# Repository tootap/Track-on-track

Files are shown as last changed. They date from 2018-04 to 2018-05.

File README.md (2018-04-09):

# Track-on-track

This is our ECE 477 senior design project.

Track-on-Track is a project which helps users to find their belongings. It is placed with a user’s belonging and uses a GSM module to connect with a phone app which shows the location of the device. A smartphone application will be available to allow the user to interact with the device but it can also be interacted with through GSM.  When the device is in shorter range, it uses a bluetooth module and shows on the app whether the user is getting closer to the device. The user will be able to see the device’s location, activate a sound alarm on the device, and manipulate the devices settings remotely. The user will also be able to interact with the device’s settings through various buttons and an LCD on the device.

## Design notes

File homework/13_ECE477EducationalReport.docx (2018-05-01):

## Purdue ECE Senior Design Semester Report

Course Number and Title | ECE 477 Digital Systems Senior Design Project
Semester / Year | Spring 2018
Advisors | Prof. Thottethodi, George Hadley
Team Number | 16
Project Title | Track-on-Track

##### Senior Design Students – Team Composition

Name | Major | Area(s) of Expertise Utilized in Project | Expected Graduation Date
Nicholas Geirland | CmpE | Firmware, Soldering | Spring 2018
Nathan McNally | CmpE | Software | Spring 2018
Yunsheng Li | EE | Schematics, PCB Layout | Spring 2018
Aaron Kaiser | CmpE | Software, Design | Spring 2018

Project Description: Provide a brief (2-3 page) technical description of the design project, as outlined below:

(a) Summary of the project, including customer, purpose, specifications, and a summary of the approach.

Track-on-track is a project designed to create a device which is capable of transmitting its location to the user through SMS messages, and which is also able to communicate relative distance to the user through bluetooth. In addition, the device will contain a speaker which will be used for finding the device audibly. The project also included a smartphone application, which is the primary means of communicating with the user. The purpose of the device is to locate lost or stolen bags, luggage, or other containers which may contain valuables. This product is designed for anyone who carries valuables with them in bags that they would not want to lose, and in particular, it is designed for travelers. Some specifications for the project were to make it small and light enough to be able to fit into most bags and not be difficult to carry. Another major concern was battery life, as the device was supposed to go into a bag and stay there for multiple weeks at a time. Other considerations included the strength of the signal of both the cell modem and the bluetooth, as more power means a more reliable device. In the end, the GSM cell modem and bluetooth module were both chosen to balance the need for power with the need for battery life. A microcontroller was selected based on its ability to preserve power, as not many heavy calculations were required for this design.

(b) Description of how the project built upon the knowledge and skills acquired in earlier ECE coursework.

Multiple courses helped the team prepare for this design. The whole device was designed around using a microcontroller to control flow between the different communication devices, and also to interpret and answer requests from the user. ECE 362 was the introductory microcontroller course at Purdue, and it covered the basics of programming a microcontroller and using it to interface with various devices. That course also had an opportunity to learn about and produce a PCB, which was the team’s first introduction to custom making PCBs. ECE 264 is a CompE required course which covers advanced C programming. This course also introduced many structures, methods, and concepts used in computer programming. The app for this design was an android app and was programmed in Java, but even so the concepts taught in ECE 264 assisted with developing the app. ECE 201 is an introductory circuits course which teaches the basics of circuit design with components such as capacitors, inductors, and resistors. While the concepts taught in this course are very basic, they were still required when calculating values of current limiting resistors and decoupling capacitors in the circuits.

(c) Description of what new technical knowledge and skills, if any, were acquired in doing the project.

In order to make progress in the project, new skills and knowledge was learned. For the hardware, the skills to use EAGLE CAD to design schematics and PCB layout were learned. Soldering is another skill that was learned and practiced a lot for each team member when building the board. Moreover, the important skill to debug hardware in a systematic way was acquired.

For software, the knowledge of how to communicate through Bluetooth module and GSM cell modem was learned. Also, the development of phone app required team members to learn the skills to program for android systems. The knowledge of using Google Maps in project’s app was also learned.

(d) Description of how the engineering design process was incorporated into the project. Reference must be made to the following fundamental steps of the design process: establishment of objectives and criteria, analysis, synthesis, construction, testing, and evaluation.

During the establishment of objectives and criteria stage of our project, we formulated a solution to a problem that was inspired by a situation in which a team member was directly impacted. We analyzed similar solutions and defined objectives that would meet the requirements for developing a product to solve the specific problem. As the project progressed, we conducted analysis on which hardware components would best fit our needs for meeting our objectives. Continuing with synthesis and construction, we began developing initial software, firmware, and schematics. Each separate hardware and software module was tested and brought online independently until the complete system was brought to fruition. As the various components were evaluated, there arose the need to return to the construction and testing stages until we could successfully demonstrate our complete design. The device was tested in an outdoor environment to ensure the testing modeled a real life situation.

(e) Summary of how realistic design constraints were incorporated into the project (consideration of most of the following is required: economic, environmental, ethical, health & safety, social, political, sustainability, and manufacturability constraints).

## Economic: The design took the cost into consideration to ensure the device is affordable for users by choosing relatively inexpensive parts and PCB manufacturer.

## Environmental: The device was designed to have a low environmental impact, creating no waste materials and no harmful radiation. This is achieved by choosing Lithium-ion rechargeable battery which results in no wasted batteries.

Ethical: The device has the potential to be used for unethical purposes such as stalking because the purpose of the device is luggage tracking. Although this kind of use cannot be directly prevented, the design will include warning tags that outlines the lawful results of using it for criminal purposes.

## Health & Safety: The safety problems on the device come only from the battery because the Bluetooth module and the cell modem used are certified to be harmless. The design prevents the battery from bringing harms by utilizing a sturdy package.

Social: During the development of project, it was brought to our attention that it was illegal to carry devices with lithium-ion batteries in checked luggage; however, through research, it was discovered that this is not the case. Traveling with spare (non-installed) lithium-ion batteries in checked luggage is prohibited, but devices with installed batteries are accepted in checked luggage.

## Political:

## Sustainability: The device was designed to communicate with user’s smartphone with Android system. Since Android smartphones have a large popularity in users, the device can be used by tons of users and as long as the app is downloaded, the device can be used to the end of its life cycle.

Manufacturability: Assuming that all chips and passive components can be soldered onto the PCB via an automatic process. The manufacturability of the device is great. Since most of the components are on board except the battery and antennas, once the board is manufactured, the only work left is to plug in the battery and antennas. Not only the assembly of the device is simple, it is also simple to swap the battery and antennas when they stop working.

(f) Description of engineering standards utilized in the project

Both the Bluetooth and GSM cell radio used in our project are certified by the FCC and CE. These components also utilize their respective standard communication protocols allowing for communication between the device and any mobile device that communicates using the standard communication protocols for cellular or Bluetooth, or both.

(g) Description of the multidisciplinary nature of the project.

This project required computer engineering knowledge and skills. The microcontroller is programed to interface with modules and process the commands to achieve desired functionalities. The phone app required knowledge of Java language to work together with the device. Moreover, electrical engineering knowledge was also required for the project to determine the circuit schematics design and values of passive components. Finally, some technical skills were used in building the prototypes such as soldering and EAGLE CAD software to design the PCB schematics and layout.

(h) Description of project deliverables and their final status.

The final prototype was able to achieve all the desired functions. It was able to communicate with smartphones via the phone app and show the location of the device using GPS. The device was able to send text messages to smartphones. Also, the device can be controlled to make sound through Bluetooth via the app. The pushbuttons and switches can successfully communicate with the microcontroller and enable the user to interact with device’s menus.

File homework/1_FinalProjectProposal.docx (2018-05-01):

# Final Project Proposal

# Year: 2018 Semester: Spring Team: 16 Project: Track-on-Track

# Creation Date: 1/10/2018 Last Modified: 1/10/2018

# Team Members (#1 is Team Leader):

# Member 1: Nick Geirland Email: ngeirlan@purdue.edu

# Member 2: Nathan McNally Email: nmcnall@purdue.edu

# Member 3: Yunsheng Li Email: li1436@purdue.edu

# Member 4: Aaron Kaiser Email: kaiser20@purdue.edu

# 1.0 Project Description:

Track-on-Track is a project which helps users to find their belongings. It is attached to user’s belonging and uses a SIM card module to connect with a phone app which shows the locations of the device. When the device is in shorter range, it uses a Bluetooth module and shows on the app whether the user is getting closer to the device. A smartphone application will allow the user to interact with the device. The user will be able to see the device’s location, activate a sound alarm on the device, and manipulate the devices settings remotely. The user will also be able to interact with the device’s settings through various buttons and an LCD on the device.

# 2.0 Roles and Responsibilities:

Nicholas Geirland will be the team leader for the project. This will involve making sure everyone is able to work on their portions of the project while also helping out with any design issues that may rise up. He is suited for this because he has been the team leader in all of his previous Computer Engineering class projects. He has also been the vice president of the Purdue Linux User Group since the end of his freshman year so leadership isn’t a new responsibility for him.

Nathan McNally has experience with both high level and low level programming languages. He has experience in Java, C, C++, assembly, and python. He has experience programming microcontrollers as well as working with phone apps. For these reasons, he will be the software engineer of the group, assisting in both microcontroller and app programming responsibilities.

Yunsheng Li will be the hardware engineer since he is highly interested in designing PCB and hardware aspects of the project. He is good at constructing circuit boards and doing math of circuits. He designed the circuit layout for his ECE 362 project. Also, he has some experience in using EAGLE for PCB design and 3D printing.

Aaron Kaiser will be the systems engineer due to his interest and experience in dealing with integrating software and hardware. He’s good at dealing with high level problems and assessing generic issues when they arise. He’s well versed in theories and concepts and in his past ECE 337 team he was responsible for creating many systems diagrams and tackling system wide bugs.

2.1 Homework Assignment Responsibilities

Homework responsibilities are detailed in Figure 1, below.

Design Component Homework | | Professional Component Homework
3-Software Overview | NG | 9-Legal Analysis | NM
5-Electrical Overview | YL | 10-Reliability and Safety Analysis | NG
7-Mechanical Overview | NM | 11-Ethical/Environmental Analysis | YL
8-Software Formalization | AK | 12-User Manual | AK

# Figure 1: Assignment Responsibilities

NG: Nicholas Geirland NM: Nathan McNally YL: Yunsheng Li AK: Aaron Kaiser

# 3.0 Estimated Budget

Item | Estimated Cost
Mechanical
Packaging | $5.00
Electrical
SIM Card | $9.00
Cell Modem | $70.00
PCB Fabrication | $50.00
PCB Components | $30.00
Rechargeable Battery | $40.00
Microcontroller | $20.00
Bluetooth Chip | $5.00
Antennae | $15.00
Other
Shipping | $50.00
Cell Service Package (2 mo. time period) | $20.00
Total Estimated Cost | $314.00

The first section is mechanical, which includes the physical non-electrical components of the device. For this project, this only includes packaging, as this design does not include any moving parts or major physical uses. The next section is electrical, which includes all physical hardware which is involved in electrical processes. For this project, this includes things involved in communication, such as a SIM card and a bluetooth chip, in addition to basic components such as a PCB and a microcontroller. The other category includes costs associated with services rather than physical items, and for this project includes shipping costs along with a cell service package.

The project is currently within the budget of $425 given by Purdue, but additional costs may be incurred throughout the development process, as components may be more expensive than anticipated, components may be broken during the testing phases, or because the PCB may have to be remade. If costs exceed the allotment of funds, additional costs will be split evenly among team members.

# 4.0 Project Specific Success Criteria

1. An ability to communicate with the user through Bluetooth in short distances.
2. An ability to communicate with the user through a cell modem over SMS in long distances.
3. An ability to display operating mode, battery life, and cell signal through an LCD.
4. An ability to detect the devices location.
5. An ability to control the device through a smartphone application.

https://engineering.purdue.edu/ece477 Page of

ECE 477: Digital Systems Senior Design Last Modified: 03-03-2015

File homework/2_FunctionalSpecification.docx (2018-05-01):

# Functional Specification

# Year: 2018 Semester: Spring Team: 16 Project: Track-on-Track

# Creation Date: January 17, 2018 Last Modified: January 17, 2018

# Member 1: Nick Geirland Email: ngeirlan@purdue.edu

# Member 2: Nathan McNally Email: nmcnall@purdue.edu

# Member 3: Yunsheng Li Email: li1436@purdue.edu

# Member 4: Aaron Kaiser Email: kaiser20@purdue.edu

# Assignment Evaluation:

Item | Score (0-5) | Weight | Points | Notes

Assignment-Specific Items
Functional Description | | x3
Theory of Operation | | x3
Expected Usage Case | | x3
Design Constraints | | x3

Writing-Specific Items
Spelling and Grammar | | x2
Formatting and Citations | | x1
Figures and Graphs | | x2
Technical Writing Style | | x3
Total Score

# 5: Excellent 4: Good 3: Acceptable 2: Poor 1: Very Poor 0: Not attempted

# General Comments:

# Relevant overall comments about the paper will be included here

# 1.0 Functional Description

Track-on-Track is a project that helps users to find their belongings. It gathers the location information through GPS or via cellular network and communicates with the user’s cell phone. When the device is in short range with the user, the user can use the phone app to communicate to the device through Bluetooth to activate a sound alarm on the device to help find it. The battery life, cell signal strength, and its operating mode are displayed on an LCD module alongside push buttons that allow the user to change settings locally.

# 2.0 Theory of Operation

Track-on-Track will utilize a 2G cell modem to determine and communicate its location with a user via SMS messages. The cell modem will use UART to interface with the microcontroller. To ensure a secure connection between the tracking device and user’s mobile phone, a time-based one-time password (TOTP) algorithm will be implemented to verify the user with the device. For tracking purposes that are within Bluetooth range of the user, the user will be able to use a smartphone application to activate a speaker to locate the device and also use the Bluetooth signal strength to gauge the relative distance to the tracker.

Device status information will be displayed on the device’s onboard LCD. This includes battery level, airplane mode status, Bluetooth status, etc. This will communicate with the microcontroller using the UART protocol. The push buttons on the device will be able to toggle these settings on and off. Through the smartphone application, these settings will also be able to be toggled on and off if the device is within Bluetooth range.

The device will include a rechargeable lithium ion battery that will be charge through a USB connection.

# 3.0 Expected Usage Case

The tracking device will be carried around in backpacks, luggage, or suitcases, and will have to be designed with travel in mind. The device must be convenient to put in a container, meaning

that it will need to both lightweight, and of a size and shape that fits well in most backpacks. The bag it is in may provide some protection from the elements, but the device will still need to be able to handle both hot and cold environments. In addition, the device will be subject to physical stress from the bag being moved, which could include jostling, jolts, strikes against hard surfaces, and being pressed between two objects.

The device is mobile, and will require a battery to operate, and therefore battery life will have to be taken into consideration. Only one person will be using each individual device. Not much can be directly inferred about the user base, but it is known that they are physically able enough to carry a bag or suitcase. In addition, they will require a smartphone, and thus it can be assumed that they are at least somewhat familiar with technology, and are also literate enough to read and write.

# 4.0 Design Constraints

The device should have a fairly simple, rectangular boxed design with cutouts for the LCD, speaker grill, and button housings. Branding and the device’s tracking capabilities should be kept inconspicuous to prevent theft tampering in the case that the device is being utilized to recover a stolen bag. The device should be made of a lightweight material and be small enough to easily fit into a backpack, purse, suitcase, or other piece of luggage.

# 4.1 Computational Constraints

The main computational constraint of out device is the authentication algorithm that the design will use to ensure that only the actual user will be able to request the location of the device. A Time Based One-Time Password Algorithm (TOTP) is currently being considered as the algorithm of choice because the values generated according to the timer will match up even if the connection between the device and the smartphone is spotty, as the values change according to a known time. This design will not require very much memory. The only memory that will be necessary will be save user setting, and to save the ID of the device, and for this either a microcontroller with built in memory or a microcontroller that can interface with memory will be required. Information about location will have to extracted from the data sent to the device from the cell modem, but this on its own is not expected to take much processing power.

# 4.2 Electronics Constraints

The major components Track-on-Track will utilize are a GSM module, a bluetooth module, an LCD display, pushbuttons, a speaker and a battery. The anticipated interfaces for these components are UART or SPI depending on the hardware chosen. Current pin count estimations include 7 pins for the cell modem, 4 pins for the LCD, 4 pins for the bluetooth module, 3 pins for lights, 1 pin for the speaker, 3 pins for buttons, putting the total estimated pin count at 22 pins. In addition, the project will require a SIM card reader that will enable the device to use the GSM network.

# 4.3 Thermal/Power Constraints

Our device’s target operating temperature range should be similar to that of a smartphone, which ranges from approximately 32°F to 100°F[1] (https://support.apple.com/en-us/HT201678). With the use of a rechargeable, lithium-ion battery, we need to take precaution to ensure user safety by making sure the device doesn’t get too hot and doesn’t charge too quickly to compromise the battery. With this in mind, we aim to achieve a battery life up to one week by reducing power consumption as much as possible. The device should be able to complete a charge cycle overnight, so the target time to complete a full charge is eight hours or less.

# 4.4 Mechanical Constraints

Our main mechanical constraint comes from our device being portable. We want our device to be the size of a larger power bank or a larger phone with a case on it so that it can fit in most people’s backpacks, bags, and purses. Sitting in people’s bags they carry around also means we need to make sure the weight doesn’t cause a significant burden on the person carrying it.

# 4.5 Economic Constraints

Two competitive devices, TrakDot and the Geogram ONE, are priced at around $80 and $85 so we’d like to set a max price point of $100 with a hope that we can get the price down to be competitive with them. Another one of our competitors, the GeoLink OpenTracker, has a price of 99 Euros (around $120) but their device is more focused on being open to development so it has arduino compatibility and modularity. All the listed prices are for just the devices themselves, but because we and our competitors are using cell towers, the user is expected to pay for a sim card and cell service which could be up to an extra $9-20.

# 4.6 Other Constraints

The device will have to be able to be turned off for specified periods of time to comply with FAA recommendations that telephony be disabled during takeoff and landing. In addition, this will make it so that the device will conserve more battery during flights, which was a common complaint with other similar devices.

# 5.0 Sources Cited:

# [1] Apple Support. (2018). Keeping iPhone, iPad, and iPod touch within acceptable operating temperatures. [online] Available at: https://support.apple.com/en-us/HT201678 [Accessed 17 Jan. 2018].

[2] Trakdot Luggage Tracker, Flight Baggage Tracer, Anti-lost Palm-size Locator, Airline Trip Worldwide Travel Tracking Monitor Detector Finder, GSM Chip (Cell Towers), SMS Alert, iOS & Android Compatible: Electronics,” Amazon.com: Trakdot Luggage Tracker, Flight Baggage Tracer, Anti-lost Palm-size Locator, Airline Trip Worldwide Travel Tracking Monitor Detector Finder, GSM Chip (Cell Towers), SMS Alert, iOS & Android Compatible: Electronics. [Online]. Available: https://www.amazon.com/dp/B015ZASEG6. [Accessed: 17-Jan-2018].

[3] dsscircuits.com. Geogram ONE - Open Source Tracking Device [Online]. Available: http://dsscircuits.com/sale/pr (http://dsscircuits.com/sale/product/dssc0120)oduct/dssc0120 (http://dsscircuits.com/sale/product/dssc0120). [Accessed: 17-Jan-2018].

[4] GEOLINK - Online GPS/GLONASS monitoring, fleet management, assets tracking - 100% white label service. [Online]. Available: https://geolink.io/opentracker.php. [Accessed: 17-Jan-2018].

Appendix I: Functional Block Diagram

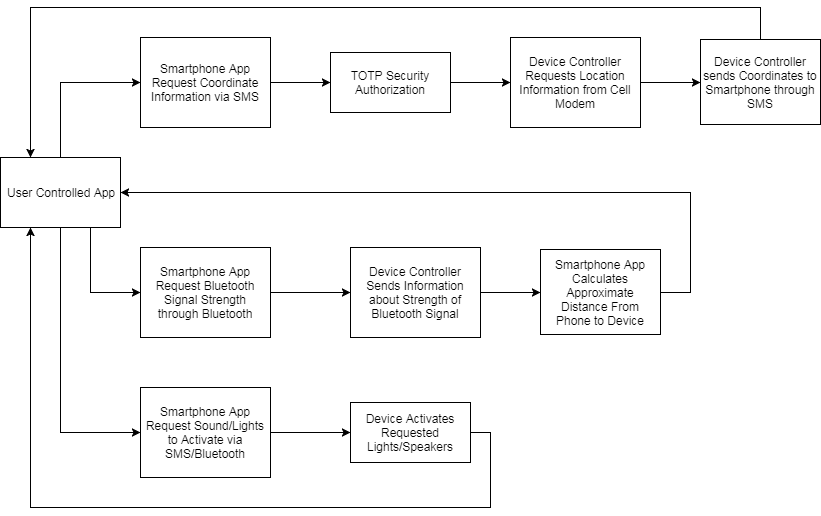
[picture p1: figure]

https://engineering.purdue.edu/ece477 Page of

ECE 477: Digital Systems Senior Design Last Modified: 11-12-2015

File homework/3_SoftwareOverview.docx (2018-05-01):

# Software Overview

# Year: 2018 Semester: Spring Team: 16 Project: Track-on-track

# Creation Date: January 24, 2018 Last Modified: January 25, 2018

# Author: Email:

Member 1: Nick Geirland Email: ngeirlan@purdue.edu

Member 2: Nathan McNally Email: nmcnall@purdue.edu

Member 3: Yunsheng Li Email: li1436@purdue.edu

Member 4: Aaron Kaiser Email: kaiser20@purdue.edu

# Assignment Evaluation:

Item | Score (0-5) | Weight | Points | Notes

Assignment-Specific Items
Software Overview | | x2
Description of Algorithms | | x2
Description of Data Structures | | x2
Program Flowcharts | | x3
State Machine Diagrams | | x3

Writing-Specific Items
Spelling and Grammar | | x2
Formatting and Citations | | x1
Figures and Graphs | | x2
Technical Writing Style | | x3
Total Score

# 5: Excellent 4: Good 3: Acceptable 2: Poor 1: Very Poor 0: Not attempted

# General Comments:

# 1.0 Software Overview

Track-On-Track will require a firmware component and a phone application software component. One main functionality of the firmware will be to wait for incoming commands from the phone application software. When an SMS message command is received, the firmware will need to securely validate the sender before issuing a response. Our initial plan for user authentication will be to use a simple password system. This way if a user does not have access to the phone originally used to communicate with the device, they can still issue commands via a different phone. A Bluetooth connection will be synced accordingly to the Bluetooth protocol. Once a connection is validated, the microcontroller’s firmware will communicate with either the GSM cell modem or Bluetooth module to retrieve the device’s GPS coordinates or connection strength, respectively.

If the request is an SMS request for GPS coordinates, the microcontroller’s firmware will construct a message that includes the coordinates and ship it off to the cell modem to be sent back to the phone application. This information will then be used with Google Maps in order to display the device’s current location to the user directly. With a Bluetooth connection, the microcontroller will need to determine the connection strength to relay back to the phone application. This information will then be displayed to the user in the form of getting ‘closer’ or ‘further’ depending on the changes in the Bluetooth signal strength. If the request is utilitarian, such as changing a setting, sounding the speaker, or displaying information, the microcontroller will update its memory, send a signal through the PWM to the speaker, or send data to the LCD using SPI.

The phone application software will need to display the location of the device on a map once it receives the coordinates from the device. It will also be required to issue commands to the device whether through SMS or Bluetooth; these commands can be used to retrieve the device’s location or to sound a speaker on the device to locate at short distances. The device’s settings will also be configurable through the application software, which includes triggering airplane mode, viewing battery life, displaying lost information on the LCD, etc.

# 2.0 Description of Algorithms

# Our firmware will need to parse the incoming request strings to determine which action to perform. It will also require a table lookup for processing the cell modem’s return codes.[1] (https://cdn-shop.adafruit.com/datasheets/SIMCOM_SIM5320_ATC_EN_V2.02.pdf)

The phone application will use Bluetooth signal strength thresholds to display approximate proximity to the device when using a Bluetooth connection. The GPS coordinates received from the cell modem will require a conversion from a raw string format to proper minute and second GPS format to be displayed by the phone application.

We will also be monitoring the rechargeable, lithium-ion battery’s charge level. Multiple threshold voltages will be set (determined by the battery’s datasheet) to display a battery life meter on the LCD to indicate if the device needs charged. This battery level will also have to be sent to the phone application upon request.

# 3.0 Description of Data Structures

All the communications between the microcontroller, the cell modem and the bluetooth module are via UART interface. The microcontroller will send display instructions to the LCD display through SPI interface. The instructions will be sent through 2G cellular network and received by the cell modem. The cell modem will convey the instructions to microcontroller. Then the microcontroller sends instructions to the cell modem to get its location information which is then transmitted to user’s phone through SMS on the same cell modem. The cell modem communicates by sending and receiving strings while usually sitting in wait but it’s also able to interrupt in the case of a text being received. The cell modem is controlled by using the AT Hayes command set [1] with significant extensions added to support all of the functionality. The commands all have their own specific return values so most output from the modem will need to be checked against constants.

# 4.0 Sources Cited:

[1] Adafruit. (2014). AT Commands Set. [online] Available at: https://cdn-shop.adafruit.com/datasheets/SIMCOM_SIM5320_ATC_EN_V2.02.pdf [Accessed 26 Jan. 2018].

# Appendix 1: Program Flowcharts

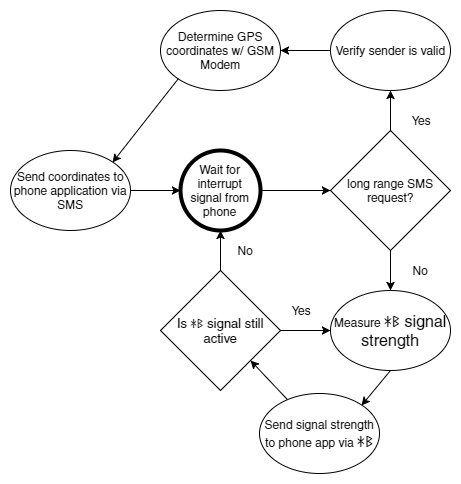
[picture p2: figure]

# Figure 1: Track-On-Track Firmware Flowchart

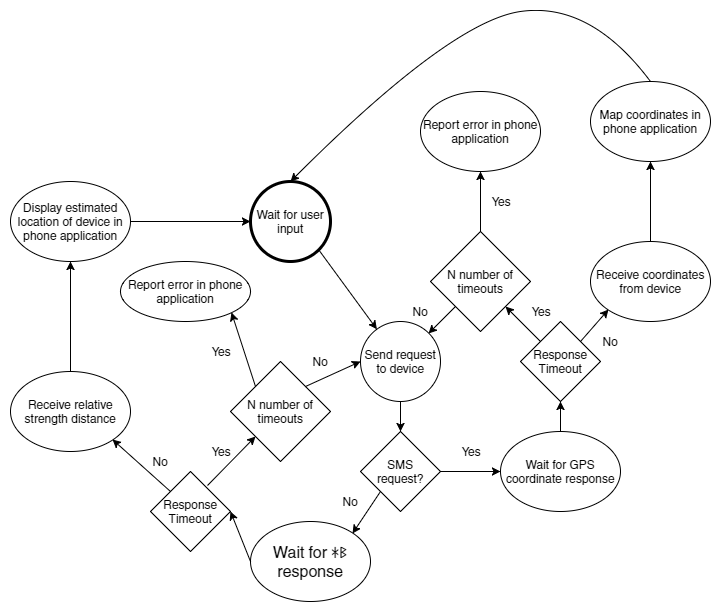
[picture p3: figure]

Figure 2: Track-On-Track Phone Application Software Flowchart

# Appendix 2: State Machine Diagrams

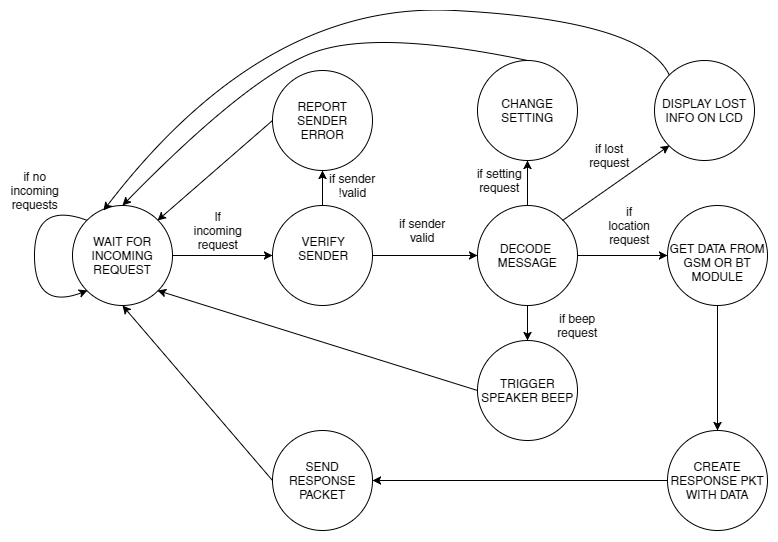
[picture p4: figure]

Figure 3: State Transition Diagram

https://engineering.purdue.edu/ece477 Page of

ECE 477: Digital Systems Senior Design Last Modified: 03-03-2015

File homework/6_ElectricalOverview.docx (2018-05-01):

# Electrical Overview

# Year: 2018 Semester: Spring Team: 16 Project: Track-on-track

# Creation Date: 1/31/2018 Last Modified: November 24, 2015

# Member 1: Nick Geirland Email: ngeirlan@purdue.edu

# Member 2: Nathan McNally Email: nmcnall@purdue.edu

# Member 3: Yunsheng Li Email: li1436@purdue.edu

# Member 4: Aaron Kaiser Email: kaiser20@purdue.edu

# Assignment Evaluation:

Item | Score (0-5) | Weight | Points | Notes

Assignment-Specific Items
Electrical Overview | | x3
Electrical Considerations | | x3
Interface Considerations | | x3
System Block Diagram | | x3

Writing-Specific Items
Spelling and Grammar | | x2
Formatting and Citations | | x1
Figures and Graphs | | x2
Technical Writing Style | | x3
Total Score

# 5: Excellent 4: Good 3: Acceptable 2: Poor 1: Very Poor 0: Not attempted

# General Comments:

# 1.0 Electrical Overview

The electrical aspect of the design for Track-on-track will revolve around the transmission of data through a usb transceiver and a cell modem. Transmission between these devices will be controlled by a 16-bit microcontroller. The microcontroller will be responsible for receiving the messages, processing them, and then sending them onward or responding to them directly. The data received from bluetooth will contain commands which must be responded to by the microcontroller. The SMS messages coming in will contain commands to the microcontroller, and in addition, can also contain requests for GPS location. If a request for location is received, the microcontroller will send a request for location to the cell modem, which will return the device’s current location. After decoding this information, the device will send the location to the user’s smartphone via SMS formulated as a set of coordinates, and it will also include battery life information. The microcontroller will also be responsible for displaying information on the LCD while the LCD is active, and for responding to requests given via the physical buttons located on the device..

Because the device is battery powered, all components will have to be powered by a battery, and thus power consumption becomes an important factor of this project. The SMS will have to check for texts at least semi-regularly, but the bluetooth transceiver will spend most of its time sitting asleep until the user sends an SMS message to wake it up, so the power draw from bluetooth will be minimal. The LCD will also have to spend most of its time off to avoid drawing power. The audio speaker connected to the device will also stay deactivated the majority of the time.

# 2.0 Electrical Considerations

1: Operating Frequencies

115200 baud will be used as the transmission rate for UART communications between the microcontroller and both the bluetooth transceiver and the cell modem. This is done because 115200 baud is the default rate for UART communications, and the design will not require faster transmission speeds.

The microprocessor will be running at a rate of 1 MHz. This speed was chosen because the benchmark for power for the chosen microcontroller, and ensuring that power use is not excessive is critical to the Track-on-track project. In addition, speeds higher than 1 MHz will not be necessary for the microcontroller, as it will be spending the majority of its time waiting for transmissions that will communicate with the microcontroller at the baud rate of 115200 baud, which is much slower than 1 MHz.

2: Power Budget

The microcontroller can run between a recommended voltage of 1.8 and 3.6 V, for the moment 2.5 V will be selected as the operating voltage because it sits well within the recommended range for safe operation. Eventually, the final voltage of the microcontroller may be lowered slightly to 2.2 V or even 2 V, as the lower the voltage is the less power is consumed. It is currently unclear if this will be feasible, however, as lowering the voltage does lower the maximum clock frequency, and it must be ensured that the microcontroller will be able to run at 1 MHz without difficulty. The current draw by the microcontroller will depend on its current operation, but with the current parameters will be between 375 µA and 110 µA.

| Voltage | Current
Microcontroller | 2.5 V | 375 µA
Bluetooth Transceiver | 3.3 V | 5 µA / 16 mA
Cell Modem | 3.3 V | 4.5 mA / 300 mA
LCD | 3.3 V | 0 A / 440 µA
Buzzer | 3.3 V | 0A / 10 mA
Total | | 4.88 mA / 326.8 mA

3: Tolerances

The microcontroller requires at least 1.8 V to operate, and it should not exceed 3.6 V. The absolute maximum voltage that can be applied to the microcontroller is 4.1 V, but the design should be well within that allotment as the voltage that will be supplied to the microcontroller will be 2.5 V.

For the LCD, no maximum voltage was given by the data sheet, it was simply stated that the recommended voltage was 3.3 V, however a maximum current of 45 mA was stated. This will not be difficult to achieve using a voltage regulated in combination with a resistor to supply power the LCD.

The cell modem requires a minimum voltage of 3.3 V, and has a recommended limit of 3.8 V. The absolute maximum is 4.2 V, but we will be well below this with an operating voltage of 3.3 V.

For the bluetooth transceiver, the supply voltage must be between 1.8 V and 3.6 V. The design will fit comfortably within that range at 3.3 V.

4: Electrical Loading Considerations

Power will be supplied to the device by a 3 cell lithium ion battery. This type of battery was chosen because it is rechargeable and has a high enough charge to power all of the components that have been selected. The battery has a charge limited voltage of 4.20 V, a nominal voltage of 3.70 V, and a discharge cutoff voltage of 2.80 V. Because of the nature of batteries varying in the level of voltage supplied, this design will also require two regulators, one for 2.5 V and another for 3.3 V. These will ensure that all components receive the correct voltage level for operation.

# 3.0 Interface Considerations

Our two main interfaces are SPI and UART. SPI will be used to control the LCD display since the LCD display only supports SPI and I2C and the microcontroller doesn’t have I2C interface available. UART will be used for both the Bluetooth module and the GSM Cell Modem because UART is easy to use and is sufficient for our needs.

For the SPI, 4 wires are used and 0.5 MHz clock will be provided, although the LCD display’s maximum clock frequency is 1 MHz, because the microcontroller is operating in 1 MHz and 0.5 MHz for LCD display is enough to provide smooth user interaction. It will have a synchronizing bit string leading the data to be transferred according to the datasheet [1] of LCD display.

For the UART, both of the UART interfaces used for cell modem and the Bluetooth will be of 115200 baud rate because this baud rate is the standard UART baud rate and it is fast enough for them to communicate.

# 4.0 Sources Cited:

[1] Mouser.com. (2017). EA DOGS104-A. [online] Available at: https://www.mouser.com/ds/2/127/dogs104e-553061.pdf [Accessed 26 Jan. 2018].

# Appendix 1: System Block Diagram

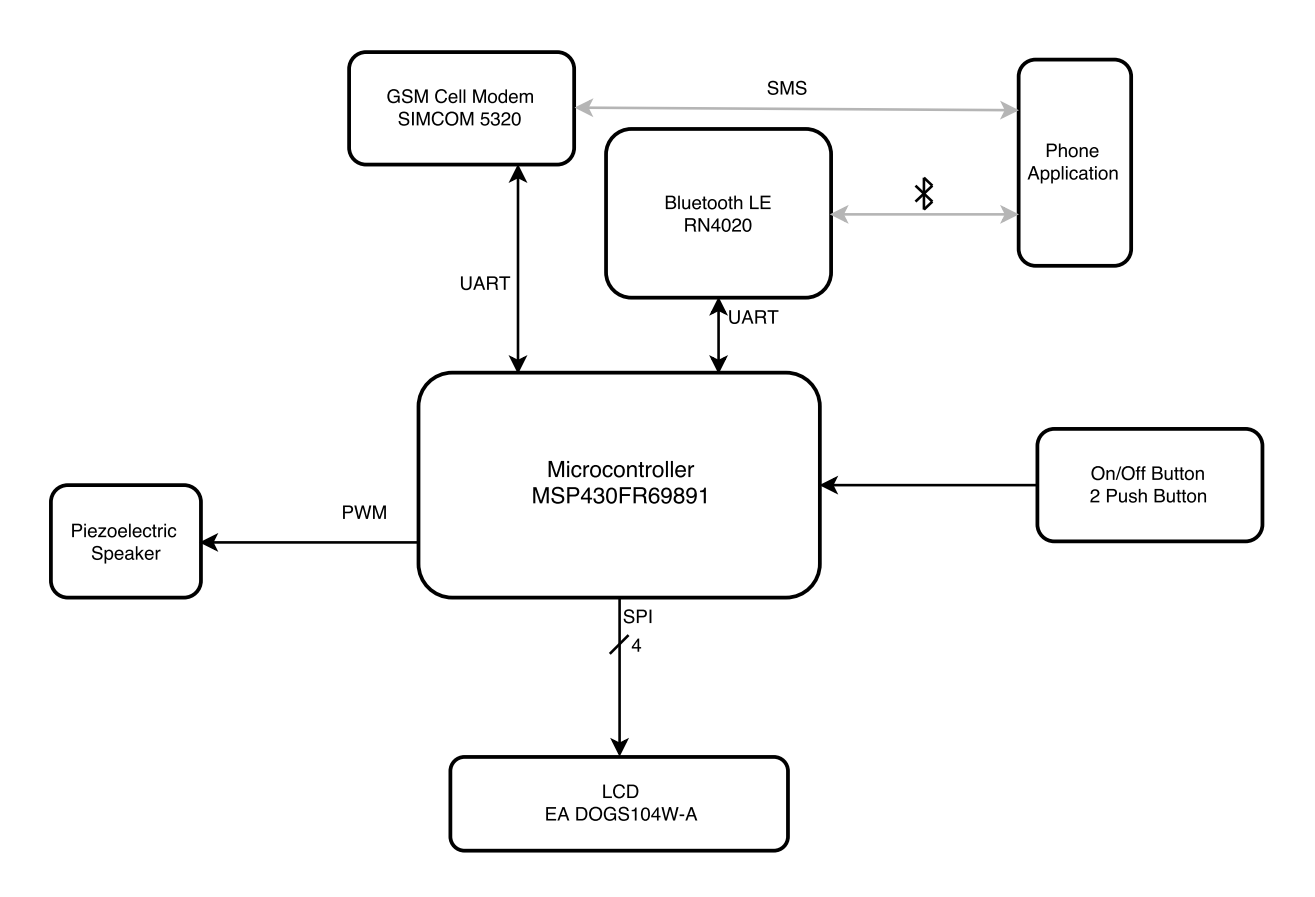
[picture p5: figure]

Figure 1: System Block Diagram

https://engineering.purdue.edu/ece477 Page of

ECE 477: Digital Systems Senior Design Last Modified: 03-03-2015

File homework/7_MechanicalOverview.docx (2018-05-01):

# Mechanical Overview

# Year: 2018 Semester: Spring Team: 16 Project: Track-on-track

# Creation Date: 2/7/2018 Last Modified: March 3, 2015

# Member 1: Nick Geirland Email: ngeirlan@purdue.edu

# Member 2: Nathan McNally Email: nmcnall@purdue.edu

# Member 3: Yunsheng Li Email: li1436@purdue.edu

# Member 4: Aaron Kaiser Email: kaiser20@purdue.edu

# Assignment Evaluation:

Item | Score (0-5) | Weight | Points | Notes

Assignment-Specific Items
Commercial Packaging Analysis 1 | | x2
Commercial Packaging Analysis 2 | | x2
CAD Model Illustrations | | x4
Project Packaging Specifications | | x2
PCB Footprint Layout | | x2

Writing-Specific Items
Spelling and Grammar | | x2
Formatting and Citations | | x1
Figures and Graphs | | x2
Technical Writing Style | | x3
Total Score

# 5: Excellent 4: Good 3: Acceptable 2: Poor 1: Very Poor 0: Not attempted

# Comments:

# Comments from the grader will be inserted here.

# 1.0 Commercial Product Packaging

# 1.1 Product #1

# A commercial product similar to our device is TrackR [1]. It provides the bluetooth function similar to our device and helps find location of device by making sound. The package of TrackR is a small round plastic piece with an LED on it.

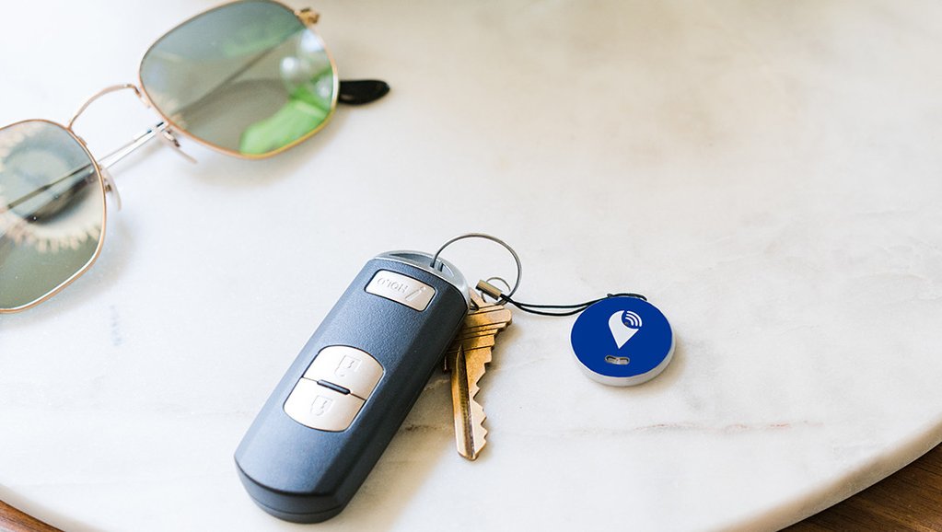
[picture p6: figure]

Fig1. Packaging of TrackR Pixel

The advantage of this package is that it is small and can be attached to everything. One of the disadvantages of this packaging is that the size limits the device to only being able to run off of very small batteries. The average battery life is only around 71 days. The small size also makes it so a physical interface would be difficult to implement, and only the smallest LCDs would be able to fit on it.

# 1.2 Product #2

Another commercial device similar to the long range tracking portion of our device is the TrakDot [2] luggage tracking device. It’s packaging is a small somewhat oblong and almost rectangular shape with rounded edges on two sides.

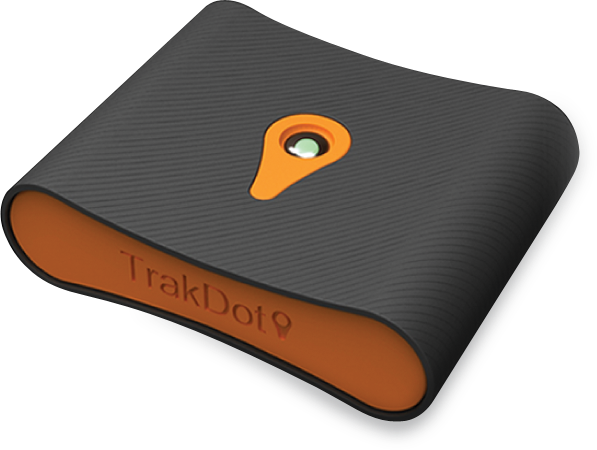
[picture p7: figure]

Figure 2: Image of exterior of TrakDot

In comparison to our design, this tracker has a much nicer and elaborate design and even has this odd shape. Our design is more focused on improving the electrical hardware and the software as it’s an ECE course so we’re only having a basic rectangular box. The TrakDot’s design is more appealing to the consumer which is useful for a commercial product. Our design does benefit from being easier to stack alongside other rectangular devices.

The only similarity in packaging between our design and the TrakDot is its general size. Not only are we differing in the general shape, we’re also providing the user a method of interfacing directly on the device with an LCD, buttons, and a switch.

# 3.0 Sources Cited

# [1] “TrackR” TrackR Pixel. [Online]. Available: https://secure.thetrackr.com/products/online-pixel-5-pack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 [Accessed: 07-Feb-2018].

[2] “Trakdot Luggage Tracker, Flight Baggage Tracer, Anti-lost Palm-size Locator, Airline Trip Worldwide Travel Tracking Monitor Detector Finder, GSM Chip (Cell Towers), SMS Alert, iOS & Android Compatible: Electronics,” Amazon.com: Trakdot Luggage Tracker, Flight Baggage Tracer, Anti-lost Palm-size Locator, Airline Trip Worldwide Travel Tracking Monitor Detector Finder, GSM Chip (Cell Towers), SMS Alert, iOS & Android Compatible: Electronics. [Online]. Available: https://www.amazon.com/dp/B015ZASEG6. [Accessed: 17-Jan-2018].

# Appendix 1: CAD Model Illustrations

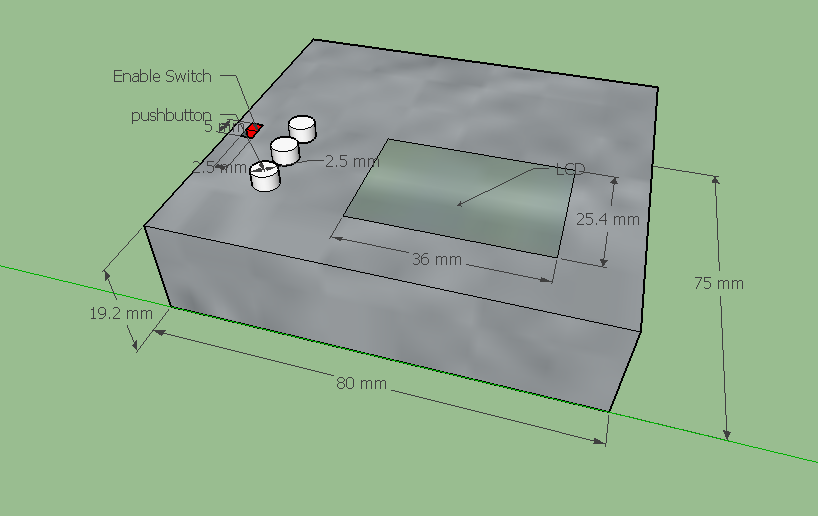
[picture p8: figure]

# Fig.1. Dimensions of Package

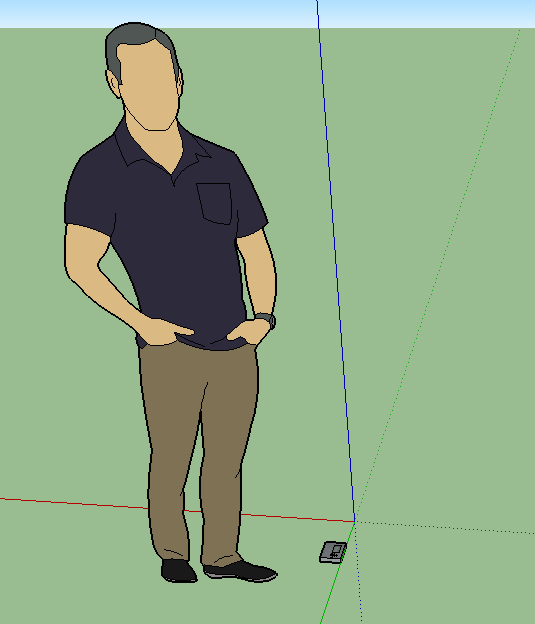
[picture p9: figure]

# Fig.2. Relative size of device (man for scale)

# Appendix 2: Project Packaging Specifications

# Include a table of project packaging specifications here. Include a materials list, tooling requirements, estimated weight, estimated unit cost, and other relevant specifications.

Material | Tools Required | Weight | Cost
polylactic acid plastic | Drill, Saw, Glue | 20 grams | $5
Screws (quantity of 4) | Screwdriver | 3 grams | $5

# Appendix 3: PCB Footprint Layout

# Provide a “rough sketch” of your PCB layout, including board dimensions, component footprint choices, and relative location of major components chosen; include relevant dimensions and area estimates for your PCB.

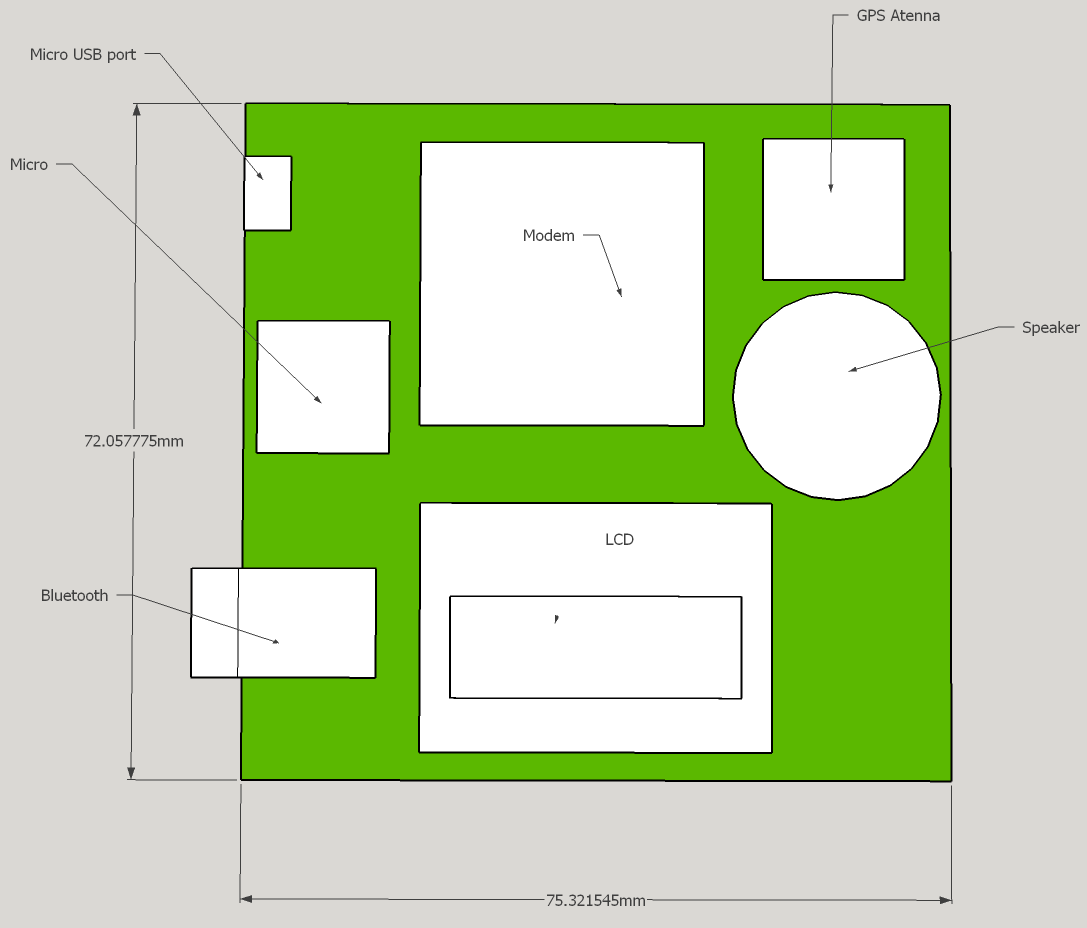
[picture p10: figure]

https://engineering.purdue.edu/ece477 Page of

ECE 477: Digital Systems Senior Design Project v1.0

ECE 477: Digital Systems Senior Design Project Last Modified: 03-03-2015

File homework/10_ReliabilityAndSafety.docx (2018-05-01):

# Reliability and Safety Analysis

# Year: 2018 Semester: Spring Team: 16 Project: Track-on-Track

# Creation Date: March 28, 2018 Last Modified: March 28, 2015

# Member 1: Nick Geirland Email: ngeirlan@purdue.edu

# Member 2: Nathan McNally Email: nmcnall@purdue.edu

# Member 3: Yunsheng Li Email: li1436@purdue.edu

# Member 4: Aaron Kaiser Email: kaiser20@purdue.edu

# Assignment Evaluation:

Item | Score (0-5) | Weight | Points | Notes

Assignment-Specific Items
Reliability Analysis | | x2
MTTF Tables | | x3
FMECA Analysis | | x2
Schematic of Functional Blocks (Appendix A) | | x2
FMECA Worksheet (Appendix B) | | x3

Writing-Specific Items
Spelling and Grammar | | x2
Formatting and Citations | | x1
Figures and Graphs | | x2
Technical Writing Style | | x3
Total Score

# 5: Excellent 4: Good 3: Acceptable 2: Poor 1: Very Poor 0: Not attempted

# Comments:

# 1.0 Reliability Analysis

Our projects microcontroller, voltage regulator, and bluetooth module were chosen for the reliability analysis. The micro controls the entire system and has a high complexity so it’s failure will have a great impact on the device. The voltage regulator was chosen because of its function to deliver the proper voltage to the entire system. If it were to fail, other components may receive incorrect voltage levels, resulting in digital logic miscalculations or component failures. The bluetooth module was also chosen because of its complexity and critical role of being the communicator between the device and the mobile application.

The model to estimate the failure rate per million hours for was taken from the MIL-HDBK-217F handbook[4]:

λP = (C1πT + C2πE)πQπL

The mean time to failure for one component is calculated by:

MTTF = 10⁶ / (24 * 365 * λP) years

Some of the values, such as C1 for the bluetooth module, were estimated because the number of gates for the module were not listed on the datasheet.

Table 1. MSP430FR6989 - Microcontroller[2]

Parameter Name | Description | Value | Comments
C1 | Die Complexity Failure Rate | .28 | Failure rate for 16-bit microcontroller given by MIL-HDBK-217F
πT | Temperature Factor | .98 | From MIL-HDBK-217F, with a temperature of 85°C, the maximum recommended operating temperature.
C2 | Package Failure Rate | .052 | 100 pin microcontroller that is non-hermetic
πE | Environment Factor | .5 | GB
πQ | Quality Factor | 10 | Commercial Component
πL | Learning Factor | 1 | Product is designed for more than 2 years in production
λP | Failure Rate Per Million Hours | 3.004
MTTF | Mean Time To Failure | 332889.4807 | Approx. 38 years to failure

Table 2. REG710NA - 2.5 Voltage Regulator [1]

Parameter Name | Description | Value | Comments
C1 | Die Complexity Failure Rate | .010 | Estimated 1 to 100 transistors used, value obtained from MIL-HDBK-217F page 5-3
πT | Temperature Factor | 5.6 | TJ = 150C
C2 | Package Failure Rate | .0019 | 6 pins
πE | Environment Factor | 4.0 | GM for mobile devices
πQ | Quality Factor | 10 | Commercial Component
πL | Learning Factor | 1.0 | > 2 years in production
λP | Failure Rate Per Million Hours | 0.636
MTTF | Mean Time To Failure | 1,572,327.044 | Approximately 179 years to failure

Table 3. RN4020 - Bluetooth Module[3]

Parameter Name | Description | Value | Comments
C1 | Die Complexity Failure Rate | .08 | Estimated number of gates to be 30,000 to 60,000 to safely estimate the highest failure rate per million hours
πT | Temperature Factor | .98 | From MIL-HDBK-217F, with a temperature of 85°C, the maximum recommended operating temperature.
C2 | Package Failure Rate | .0079 | 22 functional pins
πE | Environment Factor | 4.0 | GM for mobile devices
πQ | Quality Factor | 10 | Commercial Component
πL | Learning Factor | 1 | Product is designed for more than 2 years in production
λP | Failure Rate Per Million Hours | 0.8235
MTTF | Mean Time To Failure | 1,214,329.083 | Approximately 138 years to failure

With these estimates, the reliability of our product is proven to be acceptable. With the exception of the microcontroller, these estimates point to well over one hundred years before a failure. One way to increase the reliability of the micro would be to find a slightly more simplistic design that still meets the needs of our product.

# 2.0 Failure Mode, Effects, and Criticality Analysis (FMECA)

There are three criticality levels for this project, which are low, medium and high. High refers to failures that can cause injuries to users such as burning or battery exploding. Medium refers to failures that makes the device inoperable such as battery not being charged and being unable to communicate with users’ cell phone. Low means that some inconvenience for users is introduced such as the LCD screen fails, the pushbutton fails and bluetooth or cell modem modules fail. The failure rate required for high criticality level is at most 10e-9 per unit*hour and the failure rate required for medium and low criticality is at most 10e-6 per unit*hour. We assume the device is not opened or modified by user.

# 3.0 Sources Cited:

# 1. Ti.com. (2018). [online] Available at: http://www.ti.com/lit/ds/symlink/reg71050.pdf [Accessed 28 Mar. 2018].

2. Ti.com. (2018). MSP430FR6989 16 MHz ULP Microcontroller. [online] Available at: http://www.ti.com/lit/ds/symlink/msp430fr6989.pdf [Accessed 30 Mar. 2018].
3. ww1.microchip.com. (2018). RN4020 Bluetooth Low Energy Module. [online] Available at: http://ww1.microchip.com/downloads/en/DeviceDoc/50002279B.pdf [Accessed 30 Mar. 2018].
4. Engineering.purdue.edu. (1990). Military Handbook Reliability Prediction of Electronic Equipment. [online] Available at: https://engineering.purdue.edu/ece477/Course/Assignments/Reference/Mil_Hdbk_217F.pdf [Accessed 30 Mar. 2018].

# Appendix A: Schematic Functional Blocks

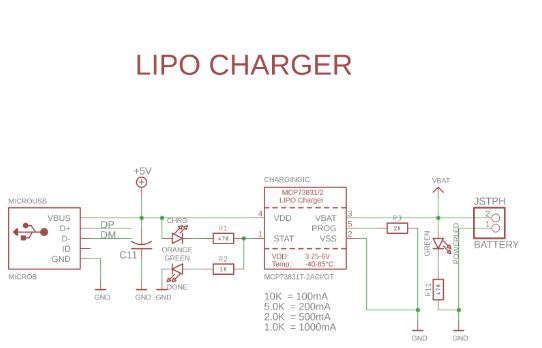
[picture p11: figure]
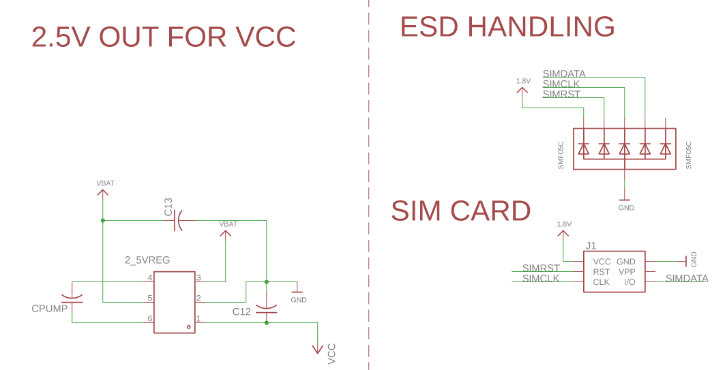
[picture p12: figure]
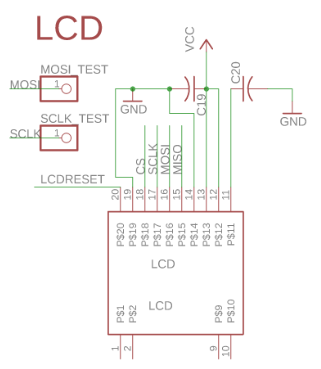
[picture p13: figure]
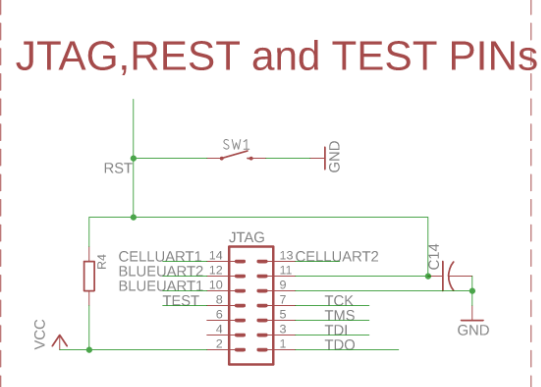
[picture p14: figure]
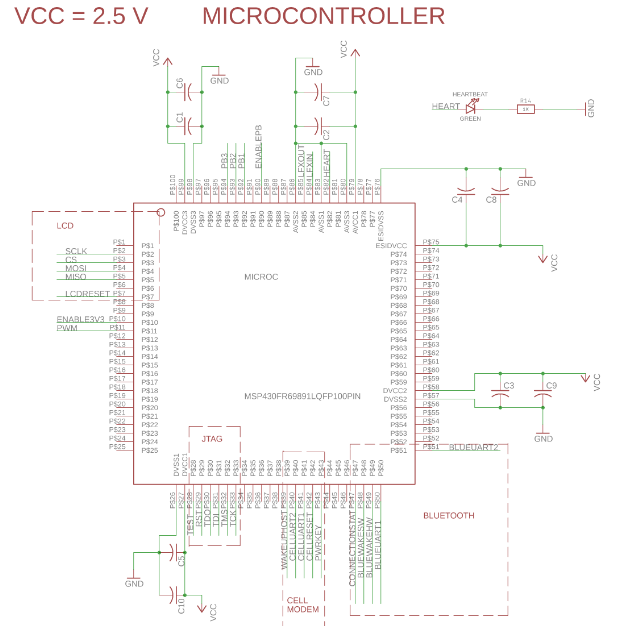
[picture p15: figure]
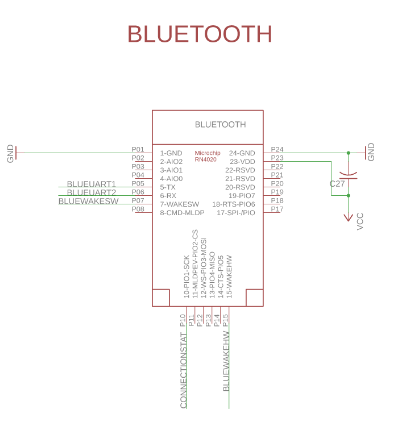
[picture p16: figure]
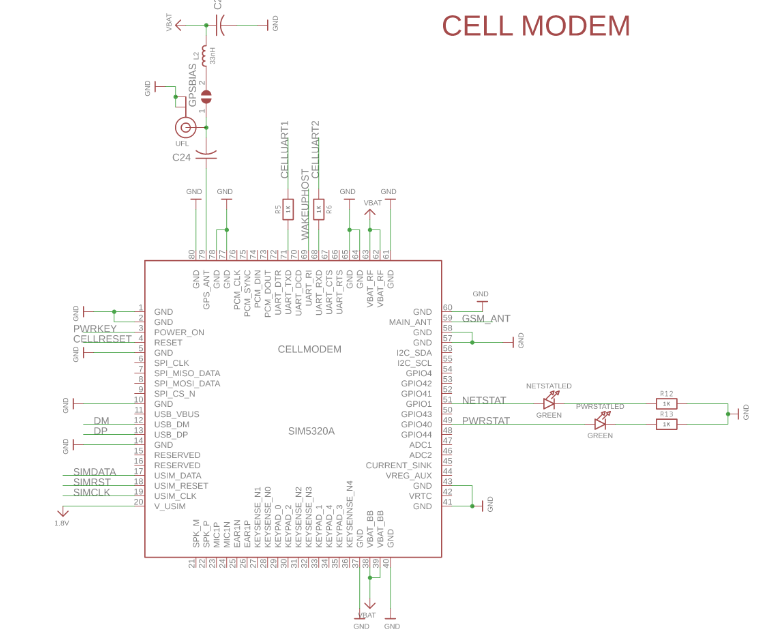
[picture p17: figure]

# Appendix B: FMECA Worksheet

Table 3. lithium-ion polymer Battery Charging Circuit FMECA

Failure No. | Failure Mode | Possible Causes | Failure Effects | Method of Detection | Criticality | Remarks
1 | Vdd connected to both 5V and ground | C11 fails short | Power trace can be burned | Add a PTC fuse in series | Medium | The device cannot be charged
2 | Battery is not charged | Vdd = 0, charging IC damaged | Battery cannot be charged | Observation, device stops to run | Medium
3 | Battery catch on fire or explode | Charging IC fails and gives too much current, battery punctured | User might be hurt | Observation | High | Make the device package sturdy

Table 4. 3.7V to 2.5V Buck Regulator FMECA

Failure No. | Failure Mode | Possible Causes | Failure Effects | Method of Detection | Criticality | Remarks
4 | Vcc = 0 | Vbat = 0, C12 fails short | System loses power | Observation, device doesn’t work at all | Medium
5 | Vcc = 3.7 V | Regulator fails | Microcontroller is fed with more voltage than designed which might overheat other modules | Observation | Low | The microcontroller can run with 3.7 V

Table 5. LCD Subsystem FMECA

Failure No. | Failure Mode | Possible Causes | Failure Effects | Method of Detection | Criticality | Remarks
6 | LCD doesn’t work | C19 fails short, LCD fails, LCD reset pin stuck low(active low) | User cannot interact with the device or read information from the device | Observation, LCD shows nothing or doesn’t make sense | Low | Can still help find device and maintain most of functions

Table 6. Microcontroller FMECA

Failure No. | Failure Mode | Possible Causes | Failure Effects | Method of Detection | Criticality | Remarks
7 | Vcc = 0 | Regulator circuit fails, any of the decoupling capacitor fails short | Microcontroller is off and system is inoperable | Observation, system doesn’t work | Medium

Table 7. Bluetooth module FMECA

Failure No. | Failure Mode | Possible Causes | Failure Effects | Method of Detection | Criticality | Remarks
8 | Vcc = 0 | Regulator circuit fails, C27 fails short | Bluetooth module inoperable | Observation or from software, the connection status signal is fed into a microcontroller GPI/O pin | Low
9 | Wakeup signal is stuck low | Microcontroller GPI/O pin fails | Bluetooth module doesn’t turn on | Observation, no bluetooth connection | Low

Table 8. Cell Modem module FMECA

Failure No. | Failure Mode | Possible Causes | Failure Effects | Method of Detection | Criticality | Remarks
10 | Vbat = 0 | Battery has no charge, decoupling capacitors fail short | Cell modem module inoperable | Observation, status LEDs off | Low
11 | No GPS signal | Antenna fails,uFL connector fails | Cell modem cannot get GPS location | Observation,cannot get GPS location | Low
12 | Cannot send GSM message | Antenna fails, SMA connector fails | Cell modem cannot communicate with user’s cell phone | Observation, cannot receive text message on cell phone | Low

Table 9. JTAG and Reset Circuit for microcontroller FMECA

Failure No. | Failure Mode | Possible Causes | Failure Effects | Method of Detection | Criticality | Remarks
13 | Reset is stuck low | Reset pushbutton damaged | Microcontroller is inoperable | Observation | Medium | Renders system inoperable
14 | No input from JTAG pins | Any of the JTAG pin connection is damaged | Cannot program microcontroller | Observation | Low | User doesn’t need to reprogram the device

https://engineering.purdue.edu/ece477 Page of

https://engineering.purdue.edu/ECE477 Page of

ECE 477: Digital Systems Senior Design Last Modified: 03-03-2015

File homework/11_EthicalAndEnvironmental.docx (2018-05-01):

# Ethical and Environmental Analysis

# Year: 2018 Semester: Spring Team: 16 Project: Track-on-track

# Creation Date: 4/4/2018 Last Modified: April 4, 2015

# Member 1: Nick Geirland Email: ngeirlan@purdue.edu

# Member 2: Nathan McNally Email: nmcnall@purdue.edu

# Member 3: Yunsheng Li Email: li1436@purdue.edu

# Member 4: Aaron Kaiser Email: kaiser20@purdue.edu

# Assignment Evaluation:

Item | Score (0-5) | Weight | Points | Notes

Assignment-Specific Items
Environmental Impact | | x6
Ethical Challenges | | x6

Writing-Specific Items
Spelling and Grammar | | x2
Formatting and Citations | | x1
Figures and Graphs | | x2
Technical Writing Style | | x3
Total Score

# 5: Excellent 4: Good 3: Acceptable 2: Poor 1: Very Poor 0: Not attempted

# Comments:

# 1.0 Environmental Impact Analysis

While in operation, the Track-on-track device poses very little threat to the environment. However, the device does have some environmental impact both during manufacture and at its end-of-life state. Individually, the components of the device that pose the biggest environmental threat are the PCB, the lithium-ion battery, and the LCD display.

During manufacture of the components that go into the Track-on-track device, several processes are used that have a significant environmental impact. The process of creating a PCB is particularly dangerous for the environment. For starters, a tin-lead alloy is commonly used to coat the copper of the PCB to protect it from oxidation [1]. Once the patterning is complete, the tin-lead alloy is removed by using a strong acidic liquid, but this leaves a waste product which consists of a highly acidic solution with tin and lead dissolved in it. This waste solution cannot be reused more than a few times, and once it is done, it is almost impossible to dispose of it responsibly [1]. In addition, the creation of vias in the circuit board requires the electroplating of copper onto the sides of the new holes. This process involves the use of a solution containing metal ions, chelates, and formaldehyde [1]. Typical disposal of the waste solution from this product involves diluting it with water until the particle levels meet regulation standard, but this is already expensive and with increasing regulation standards, it may soon become unviable. All these processes also use a lot of water, which puts a burden on local waterways.

The lithium-ion battery is another component that has an environmental cost to produce. Most of the world’s lithium comes from Chile, Argentina, and Bolivia, and the mining process itself is destructive to the environment [2]. Another problem is that the amount of lithium coming out of this area is not longer enough to satisfy the worldwide demand. New mines have been opened in Australia, but the lithium mined there is in a form that requires more processing before it can be used in batteries, which means it wastes a lot more energy, which in turn puts greater stress on the environment [2].

Liquid crystal displays (LCDs) were originally marketed as being more environmentally friendly than CRT displays; however, they still have an impact from mercury and arsenic, both of which are potentially dangerous to humans and the environment.[3] Mercury requires special regulation for disposal in certain countries and the various gases (NF3, SF6, SiH4, etc.) used during the manufacturing process also release hazardous emissions but are cheap to use. [3] Besides requiring environmentally damaging compound for manufacturing, LCD panels, compared to other displays, exhibit the highest inefficiency. They filter white light from a background source to allow only certain colors to be displayed, which is highly power consuming, and roughly 10-20% of the light energy produced by the source is used in the actual display after filtering. [3] The end-of-life period for a LCD introduces the potential for toxic chemicals to find their way to soil and water in tropical conditions. Moreover, LCD panels are very difficult to biodegrade and the liquid crystal itself can emit toxic gases under high heat. [3]

Earlier this year, a new recycling process for lithium-ion batteries was introduced by researchers at the University of California San Diego and Los Angeles that uses half the energy of the conventional process. [4] This new procedure produces compounds that are ready to be implemented in a new battery, whereas, the old process broke down cathodes into separate elements that would later have to be rebonded. The standard procedure involves crushing the batteries and then either melting or dissolving them in acid, which is also potentially dangerous to the environment. The new method requires removing the cathode material, soaking it in hot lithium, drying it to create a powder, quickly heating it to 800°C, and then finally slowly cooling it back down. [4] This process restores and reintroduces lithium into the cathode’s atomic structure. After testing this procedure on batteries that had lost half their energy storage capacity, the researchers found the recycled cathodes had the same energy storage capacity, charging time, and lifetime as the original cathodes. [4] In addition to the research team at the University of California, two other companies are also pursuing similar lithium-ion battery recycling techniques while also trying to scale up the process.

If we were to implement such a recycling process for our batteries, then we would have a potentially lesser impact on the environment. Warning labels should also be printed on the device indicating to users not to dispose of the device by throwing it in the trash, which is common in almost all consumer electronics. This will help alleviate some of the dangerous chemicals and compounds from entering landfills. It is most likely that the battery will be the first component to degrade in our device; therefore, implementing the battery in a way that will make it easily replaced by the user will allow our product to have an increased lifespan.

# 2.0 Ethical Challenges

By using our device as intended, no ethical concerns are to be raised; however, our device has the potential to be used with malicious intent. While our project is intended to be used as a tracking device for personal luggage and bags, it also has the potential to be used as tracking device for any other situation. Its small size and ability to retain a battery charge for a significant duration, only assist in its ability to be used as a malicious tracking device that’s commercially available. This includes, but is not limited to: stalkers tracking victims, criminal assailants tracking victims, and general tracking of persons unknowingly without their consent. Unfortunately, there is no effective way to prevent this kind of use, other than try to mitigate it by placing warnings in the product manual that clearly outline the lawful actions that will be taken if used with ill-intention.

Another concern is for the possibility of the included lithium-ion battery to be tampered with or used in an inappropriate environment. With the potential to be used as an explosive, it’s very important that the proper warning labels and cautions are provided to the end user. By implementing the battery in such a way that makes it hard for the user to access, these concerns could be lessened; however, this then conflicts with our environmental concerns to make the battery easily replaceable, so a whole device doesn’t require replacement when the battery reaches its end-of-life.

# 3.0 Sources Cited

# 1. M. Goosey, “Environmental best practice in the PCB industry,” Circuit World, vol. 26,

# no. 3., 2000

2. S. Hacker, “How Green are Home Batteries? The Environmental Impact of Lithium-Ion,”

pickmysolar, 03-Mar-2018. [Online]. Available:

https://blog.pickmysolar.com/how-green-are-home-batteries-the-environmental-impact-of-lithium-ion. [Accessed: 04-Apr-2018].

3. Tyagi, A. and Chatterjee, S. (2013). Liquid Crystal Display: Environment & Technology. [online] Ijestr.org. Available at: http://www.ijestr.org/IJESTR_Vol.%201,%20No.%207,%20July%202013/Liquid%20Crystal%20Display.pdf [Accessed 6 Apr. 2018].
4. IEEE Spectrum: Technology, Engineering, and Science News. (2018). Simple, Energy-Efficient Recycling Process for Lithium-Ion Batteries. [online] Available at: https://spectrum.ieee.org/energywise/energy/environment/simple-energyefficient-recycling-process-for-lithiumion-cathodes [Accessed 7 Apr. 2018].

https://engineering.purdue.edu/ece477 Page of

ECE 477: Digital Systems Senior Design Last Modified: 03-03-2015

ECE 477 Digital Systems Senior Design Project Rev 9/12

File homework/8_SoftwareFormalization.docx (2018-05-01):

# Software Formalization

# Year: 2018 Semester: Spring Team: 16 Project: Track-on-track

# Creation Date: 2/21/2018 Last Modified: March 3, 2015

# Member 1: Nick Geirland Email: ngeirlan@purdue.edu

# Member 2: Nathan McNally Email: nmcnall@purdue.edu

# Member 3: Yunsheng Li Email: li1436@purdue.edu

# Member 4: Aaron Kaiser Email: kaiser20@purdue.edu

# Assignment Evaluation:

Item | Score (0-5) | Weight | Points | Notes

Assignment-Specific Items
Third Party Software | | x2
Description of Components | | X3
Testing Plan | | x3
Software Component Diagram | | x4

Writing-Specific Items
Spelling and Grammar | | x2
Formatting and Citations | | x1
Figures and Graphs | | x2
Technical Writing Style | | x3
Total Score

# 5: Excellent 4: Good 3: Acceptable 2: Poor 1: Very Poor 0: Not attempted

# General Comments:

# 1.0 Utilization of Third Party Software

Name | License | Description | Use
MSP430FR6989 Library | BSD | Standard register and bit definitions for the Texas Instruments MSP430 microcontroller. This file supports assembler and C development for MSP430FR6989 devices. | The MSP430FR6989 Library will be used to program the MSP430 microcontroller. The library will be used to facilitate communication between the microcontroller and the peripherals.
Android Development Library | Apache 2.0 License | “The primary purposes of Android are to create an open software platform available for carriers, OEMs, and developers to make their innovative ideas a reality and to introduce a successful, real-world product that improves the mobile experience for users.” [3] | The Android Development Library is the standard library used to program Android devices. This library will be the basis for app portion of the Track-on-track project.
Google Maps Android API Utility Library | Google Maps API’s Terms of Service | “Looking for advanced features to add to your maps? The Google Maps Android API Utility Library is an open-source library of classes that are useful for a range of applications.” [1] | The Google Maps Android API Utility Library will be the main tool used to add Google Maps support to the app. Google Maps will be used to plot the location of the Track-on-track device on request.

# 2.0 Description of Software Components

The major components of the software will include: a smartphone app, functions to communicate with the cell modem, functions to communicate with the bluetooth module, and functions to communicate with the LCD and other miscellaneous activities.

The smartphone app will be used as the primary way for the user to communicate with the Track-on-track device. First of all, the app will have to prompt the user for all required permission. Once permissions are given, communication can begin. A text which is sent from the device can take several different forms. All request information will be sent in 1 text, which will consist of a series of delimited commands, with the position of the command defining what information or setting is being referred to. Each command will either be set to a value which tells the device to ignore that specific command, or a value which tells it not to ignore that command. The text will be sent by the press of a single button, and the contents of the text will be defined by the user in a secondary menu using a series of checkboxes. SMS messages received by the app will be in a similar format, except they will contain the requested information. Once the information is received, if GPS coordinate data was received, the app will parse it and use a Google Maps plugin to display the current location to the user. Other information such as battery life will be displayed, and changes to the state of the device will be answered by simple values which will refer to whether or not the device was able to change its state successfully or not. Bluetooth will have its own screen, and it will have a graphic to display whether the strength of the bluetooth signal is growing stronger or weaker. In addition, bluetooth will also have some options to send commands to the device.

Inside of the firmware, all code will be developed by us using the library developed by TI that defines register locations for our specific micro. The portions of the firmware that deal with communicating to the cell modem mainly focus over being a middle man between the android app and the cell modem. When the cell modem receives an SMS, it sends a message over UART to the micro which will wake it up from low power mode. From there, the micro should process the request, gather whatever information it will need to return from the cell modem, and send that back to the android app. Most of the time the information it needs to gather will involve either the location information of the device or of diagnostic information like battery level. The android app should also be capable of controlling settings of the device such as controlling the Bluetooth module, LCD, changing other settings in the device. If the request requires information to be returned then the software will format the data and send it back through SMS. This code will have to keep track of the commands that the GSM modem uses which is the Hayes or AT Command set.

The Bluetooth portions of the firmware are very similar to the portions that communicate with the cell modem. The code will be using most of the same functions and even many of the same configurations as both the GSM modem and the Bluetooth module both use UART with a 115200 baud rate. The major difference between the two sections of code is how to decode the communication between each module. The RN4020 module uses its own separate set of commands that are tailored more towards the functions of Bluetooth.

The LCD portion of the firmware is the simplest out of all of them. The LCD uses SPI to communicate with the microcontroller but, unlike the other two modules, isn’t complex enough to have something that can be considered its own command set. The code is also broken up into initialization and loop code. The majority of the code will be focused on keeping a menu that the user can interact with while the LCD is on. This menu will mainly be focused on allowing the user to change various settings around the board and will take input through the pushbuttons on the device. The input pushbuttons involve setting input interrupts and servicing them whenever the onboard switch is no longer in the lock position. The device also has a function to handle playing a loud noise through the speaker on board so it can be found. This function mainly involves setting the PWM of the device on the pin that’s connected to the speaker until we get a request to stop. The device also uses authentication from the user for the SMS portion of the device to prevent anyone from accessing the users location just by knowing their phone number. The device needs to be able to store the authentication passcode and offer the ability to request to change it through SMS or bluetooth.

# 3.0 Testing Plan

Each software component will need to be tested individual to confirm proper functioning before testing how multiple components function together. The tests will be conducted as follows:

Smartphone App

1. Attempt to send SMS message from app to known phone number with a variety of options set. The output to the other phone will be checked against the theoretical output. This test will be repeated several times in order to ensure all options function as expected.
2. Attempt to send SMS message from phone to app with a variety of options set. This test will ensure that the app can receive and properly display coordinates via the Google Maps plugin.
3. Connect to another bluetooth device, and then move the phone away from and closer to the source of the other bluetooth device. This will test whether or not the app can properly display whether the strength of the bluetooth signal is getting stronger and weaker.
4. Connect to another bluetooth device and attempt to send and receive messages. This test will prove that the app is capable of both sending and receiving information through bluetooth.

GSM Modem

1. Send SMS messages with different requests and test to make sure that the device is capable of responding back.
2. Request for location and check to make sure that it can send the location back through SMS.
3. Request to change settings such as turning Bluetooth, LCD on, or changing the authentication.
4. Request without correct authentication unlike the above three steps.
5. Test all of the above in multiple combinations to make sure they don’t interfere with each other.

Bluetooth

1. Check if the device can connect with an android phone.
2. Attempt to request the device to alert by playing noise through the speaker.
3. Request to change settings such as turning Bluetooth off, turning on the LCD, or changing the authentication.
4. Test the above in multiple combinations to make sure they don’t interfere with each other.

LCD/Miscellaneous

1. Check the lock switch to make sure it can’t be turned on when it’s not meant to be.
2. Make sure the menu can be displayed and changed correctly when the buttons are pressed and unlocked.
3. Test the alert noise and make sure it can make a significant enough noise.
4. Attempt to change the authentication and make sure it can still work with the updated authentication.

# 4.0 Sources Cited:

[1] “Google Maps Android API Utility Library,” Google Developers, 07-Jun-2017. [Online].

Available: https://developers.google.com/maps/documentation/android-api/utility/.

[Accessed: 21-Feb-2018].

[2] “MSP430FR6989 LaunchPad™ Development Kit,” Texas Instruments, Jul-2015. [Online].

Available: http://www.ti.com/lit/ug/slau627a/slau627a.pdf. [Accessed: 21-Feb-2018].

[3] “The Android Source Code,” Android Source, 14-Nov-2017. [Online]. Available:

https://source.android.com/setup/. [Accessed: 21-Feb-2018].

# Appendix 1: Software Component Diagram

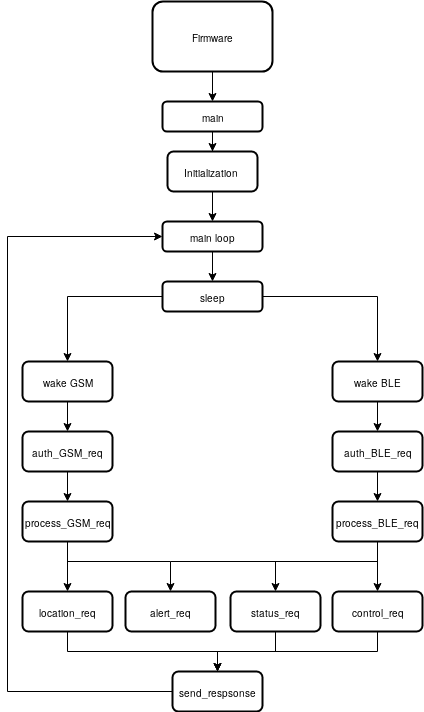
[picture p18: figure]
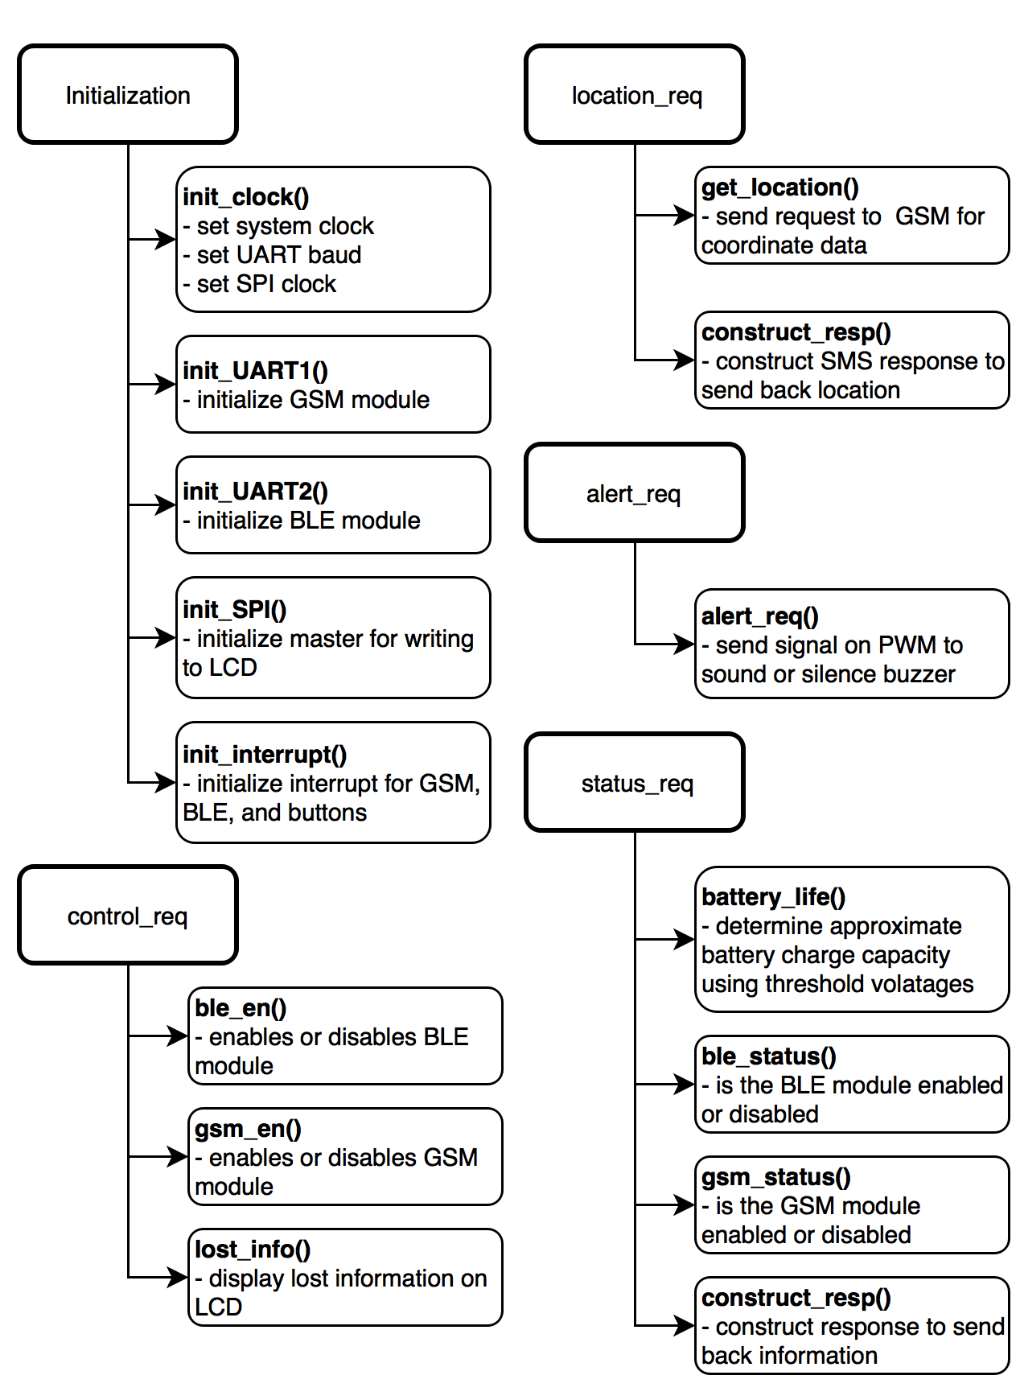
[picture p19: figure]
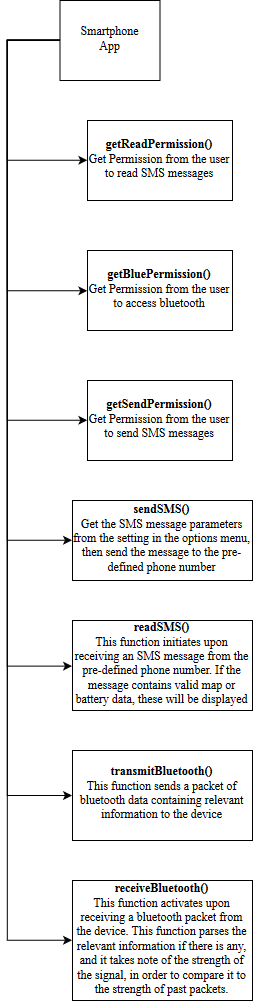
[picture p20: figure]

https://engineering.purdue.edu/ece477 Page of

ECE 477: Digital Systems Senior Design Last Modified: 03-03-2015

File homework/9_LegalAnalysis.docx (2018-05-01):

# Legal Analysis

# Year: 2018 Semester: Spring Team: 16 Project: Track-on-Track

# Creation Date: March 21, 2018 Last Modified: March 3, 2015

# Member 1: Nick Geirland Email: ngeirlan@purdue.edu

# Member 2: Nathan McNally Email: nmcnall@purdue.edu

# Member 3: Yunsheng Li Email: li1436@purdue.edu

# Member 4: Aaron Kaiser Email: kaiser20@purdue.edu

# Assignment Evaluation:

Item | Score (0-5) | Weight | Points | Notes

Assignment-Specific Items
Regulatory Analysis | | x3
Analysis of Patent 1 | | x3
Analysis of Patent 2 | | x3
Analysis of Patent 3 | | x3

Writing-Specific Items
Spelling and Grammar | | x2
Formatting and Citations | | x1
Figures and Graphs | | x2
Technical Writing Style | | x3
Total Score

# 5: Excellent 4: Good 3: Acceptable 2: Poor 1: Very Poor 0: Not attempted

# Comments:

# 1.0 Regulatory Analysis

# 1.1 Federal Communications Commission (FCC)

The most important regulatory certification our project will require is from the Federal Communications Commission (FCC), since our device includes a bluetooth and GSM radio. The FCC has regulations to limit potentially dangerous interference caused by radio communications, where products that are most likely to cause interference are more heavily regulated and products that are least likely to cause interference are less heavily regulated.[1] Our bluetooth and GSM modules are both FCC certified, therefore our device can be classified as a Class B digital device and unintentional radiator.

Class B devices have stricter standards than Class A devices since they are consumer devices that are more likely to be located near other electronic devices. The regulations for Class B devices specify that a product must protect against interference caused to a receiver around ten meters away.[1] With a Class B digital device, Track-On-Track will require the FCC certification process.[4]

The first step of the certification process is to locate and send our device to a Telecommunications Certification Body (TCB), where radio frequency emissions will be measured. Once tests conclude the device complies with FCC standards, an FCC ID is assigned to the device. This ID must be permanently marked on the device or on a tag that is permanently attached to the device.[1]

1.2 Conformité Européenne (CE)

The CE marking will allow us to market and sell our product with the confines of the European Economic Area.[2] The CE marking is designed to have a much broader scope than FCC regulation, covering not only electronic devices, but also covering almost every category of products sold to consumers. Specifically, however, the types of regulations for electromagnetic devices set down by the CE are similar to those set down by the FCC, with some minor changes in scope between the two. What this means is that most labs which are equipped to test for FCC regulations are also set up to test for CE regulations, and because of this we will be able to have the device tested for compliance under both standards at the same time.[3]

While the device itself would have to be tested upon completion, the main components that have to be tested are the Bluetooth module and the cell modem. Both these devices were tested by their manufacturers and have been cleared for CE regulations. Therefore, unless any other part of the device is producing electromagnetic interference, which shouldn’t be the case, the device should have no problem passing CE standards.

1.3 Underwriters Laboratory (UL)

Gaining UL certification will allow our product to be trusted as safe for consumers. With a lithium-ion battery included in our product, it is important that we gain certification that the battery is safe in all aspects including charging, storing, and transportation in consumer’s luggage and bags. UL is the world’s leader in battery safety testing with its certification recognized in the global market and they conduct multiple tests that cover all aspects of battery safety.[5]

In order for UL to conduct tests, several copies of the design under test must be sent to their labs, as many of them will be destroyed in the testing process. If the device fails UL testing, they will respond with the specific requirements it did not meet. After that, the product can be modified and submitted again for testing.[6]

# 2.0 Legal Liability Analysis

# 2.1 Analysis of U.S. Patent US9439164B2[7]

Filing Date: March 27, 2014

Abstract:

This patent covers a GSM device that is placed in checked luggage that processes and shares location data of the luggage. A mobile device is to be used in conjunction with the GSM device to alert the consumer when the luggage has arrived at the destination airport. If the GSM device does not detect it has arrived at the airport on time, it sends its location once landing at an airport to the consumer and airline.

Potential Infringements:

(1) A system for determining the location of a piece of luggage, comprising of a GSM device attached to the luggage to be tracked, a host platform communicates with the GSM device, and a mobile device communicates with the host platform.
(2) The mobile device is a cellular telephone.

This patent for TrakDot, a device that closely resembles our product, includes two claims that our product has a very high chance of infringing. Both our device and the patent’s claimed device include a system that utilizes a GSM module in order to track a device’s location that is placed in luggage. Both systems also rely on a cellular telephone in order to relay the tracking device’s location. However, this patent covers only sending location data once the tracking device is at an airport, while our device can send its location whenever the mobile device sends it a request. This patent also includes a claim for auto-disabling the tracking device’s GSM module once it detects the device is traveling at a high speed which was a potential feature for our device. If implemented this may cause more trouble with claim infringements.

# 2.2 Analysis of U.S. Patent US20100283600A1[8]

Filing Date: November 11, 2010

Abstract:

This patent covers a system for loss prevention of small items such as wallets, keys, and purses. A wireless device and small wireless tag are used where the wireless tag is attached to items to be tracked and the wireless device uses a software application to query the wireless tag.

Potential Infringements:

(1) A system for monitoring the distance between a mobile device and a tracking device that consists of a tracking device utilizing an RF radio, programmable logic, and battery where signal strength is measured periodically and filtered with an algorithm to reduce inaccuracies.

The other claims of this patent heavily cover the algorithm for determining the distance from the tracking device to the mobile device that appear much more sophisticated than our device’s feature to give a relative distance based on Bluetooth signal strength. However, our device will similarly use an RF signal’s strength the estimate if a mobile device is moving closer or farther away from the tracking device. The claim our product potentially infringes describes a very similar process to how our device gives a location using Bluetooth strength. By using a broad claim of RF radio, this patent covers many different possible ways we could track a device when in close proximity to a mobile device. This may make it difficult to get by the potential infringement.

# 2.3 Analysis of U.S Patent US20140073262A1[9]

Filing Date: March 13, 2014

Abstract:
This patent covers systems and methods to do loss prevention, discovery and tracking of personal items. The systems include a device that contains a microprocessor and communicates with user’s smart device wirelessly. It also covers the method to monitor the proximity of the device to the user by measuring the signal strength of communication. When the device is not within a certain proximity, an alert is produced.

Potential Infringements:

(1) A device that contains a microprocessor system and communicates with a smart device wirelessly.
(2) A system that checks the proximity of device using the signal strength of communication.

This patent states a system that is very similar to our project since it has the same purpose as our project and the system also communicates wirelessly. It similarly uses the signal strength to determine the proximity of device which is the same method we use for our project’s bluetooth mode. However, different from this patent’s system is that our projects does not produce an alert when the device is out of a certain range from the user. Instead, our project uses the signal strength to help find the device by making sound.

# 3.0 Sources Cited:

1. Transition.fcc.gov. (1996). UNDERSTANDING THE FCC REGULATIONS FOR COMPUTERS AND OTHER DIGITAL DEVICES. [online] Available at: http://transition.fcc.gov/Bureaus/Engineering_Technology/Documents/bulletins/oet62/oet62rev.pdf [Accessed 21 Mar. 2018].
2. “Manufacturers,” European Commission. [Online]. Available: https://ec.europa.eu/growth/single-market/ce-marking/manufacturers_en. [Accessed: 21-Mar-2018].
3. “FCC Frequently Asked Questions,” Bureau Veritas. [Online]. Available: http://www.bureauveritas.com/wps/wcm/connect/31b53f004edb713e8d5fcd600bbc220b/FCC_Frequently_Asked_Questions_Aug10.pdf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. [Accessed: 21-Mar-2018].
4. Federal Communications Commission. (2018). Equipment Authorization Procedures. [online] Available at: https://www.fcc.gov/general/equipment-authorization-procedures-0 [Accessed 21 Mar. 2018].
5. Ul.com. (2017). Battery Safety Testing and Certifications | UL. [online] Available at: https://www.ul.com/consumer-technology/en/services/safety/battery-safety-testing/ [Accessed 23 Mar. 2018].
6. UL. (2017). Product Submittal Process FAQ | UL. [online] Available at: https://www.ul.com/customer-resources/faq/product-submittal-process-faq/ [Accessed 23 Mar. 2018].
7. Patents.google.com. (2018). US9439164B2 - Luggage tracking method and apparatus - Google Patents. [online] Available at: https://patents.google.com/patent/US9439164?oq=14%2f227%2c140 [Accessed 23 Mar. 2018].
8. Patents.google.com. (2018). US20100283600A1 - Low power apparatus for preventing loss of cell phone and other high value items - Google Patents. [online] Available at: https://patents.google.com/patent/US20100283600?oq=Low+power+apparatus+for+preventing+loss+of+cell+phone [Accessed 23 Mar. 2018].
9. Patents.google.com. (2018). US20140073262A1 - Proximity tag for object tracking - Google Patents. [online] Available at: https://patents.google.com/patent/US20140073262A1/en?q=~patent%2fUS20100283600A1 [Accessed 23 Mar. 2018].

https://engineering.purdue.edu/ece477 Page of

ECE 477: Digital Systems Senior Design Last Modified: 03-03-2015

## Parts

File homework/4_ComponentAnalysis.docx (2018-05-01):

# Component Analysis

# Year: 2018 Semester: Spring Team: 16 Project: Track-on-track

# Creation Date: January 24, 2018 Last Modified: September 8, 2016

Member 1: Nick Geirland Email: ngeirlan@purdue.edu

Member 2: Nathan McNally Email: nmcnall@purdue.edu

Member 3: Yunsheng Li Email: li1436@purdue.edu

Member 4: Aaron Kaiser Email: kaiser20@purdue.edu

# Assignment Evaluation:

Item | Score (0-5) | Weight | Points | Notes

Assignment-Specific Items
Analysis of Component 1 | | x2
Analysis of Component 2 | | x2
Analysis of Component 3 | | x2
Bill of Materials | | x6

Writing-Specific Items
Spelling and Grammar | | x2
Formatting and Citations | | x1
Figures and Graphs | | x2
Technical Writing Style | | x3
Total Score

# 5: Excellent 4: Good 3: Acceptable 2: Poor 1: Very Poor 0: Not attempted

# General Comments:

# Relevant overall comments about the paper will be included here

# IMPORTANT NOTE: The Bill of Materials is a separate document and should be downloaded and filled out for another assignment. The Bill of Materials is to be submitted separately, per the course calendar (possibly on a different week), and will graded collectively with this assignment.

# 1.0 Component Analysis:

The primary hardware components of the Track-on-track project will consist of a bluetooth transceiver, a GSM cell modem, an LCD, and a microcontroller.

1. Bluetooth Transceiver: The bluetooth transceiver will be responsible for communication with the user’s smartphone at close range, and this will be used to figure out if the user is moving further away from or closer to the device, and it will also be used to issue commands to the device.
2. GSM Cell Modem: The cell modem will have two primary responsibilities, the first of which is to find the coordinates that the device is located at, and the other is to send SMS text messages to the user’s phone.
3. LCD: The LCD will be used to display information to the user about the status of the device.
4. Microcontroller: The microcontroller will be responsible for managing the peripherals of the device along with interpreting sent/received communications.

Describe briefly the components being analyzed in this section; don’t simply list components, but use no more than 1 complete sentence for each component being analyzed in your design. Analyze all major components in your design; it is expected that your design contains at minimum 3 major components.

# 1.1 Analysis of Bluetooth Transceivers:

Bluetooth is important for the device to communicate with the user at close ranges. It will assist the user in finding the device by communicating the strength of the connection, allowing the user to tell if they are getting ‘hotter’ or ‘colder’ to the location of the device. In addition, bluetooth also gives the user a way to control the device. Certain features, such as the device’s speaker, will be able to be controlled by commands sent via bluetooth. Without bluetooth, the device will only be able to send a set of coordinates to the user, which will become less useful for pinpointing the device’s specific location.

One of the design constraints is the range at which the bluetooth can connect. Because the device’s goal is to connect with the user’s smartphone from an unknown location, the longer range it can connect from the better. The range is dependant on the transmission power of the device.

This constraint must be traded off with the amount of power used by the device. Because the device is battery powered, battery life is a prime concern. Unfortunately, low power consumption bluetooth transceivers usually come with the tradeoff of low range. However, for this device the bluetooth will be disabled for long periods of time, only being enabled upon request from the user, so range will be considered more important.

Another constraint is the methods the bluetooth device offers to connect to the microcontroller. There are many ways both in protocol and in physical packaging, but for Track-on-track, a device which can connect in UART and SPI is desired.

For these constraints, the following devices were selected: RN4020 Bluetooth Low Energy Module, EYSGCNZWY Bluetooth Low Energy Module, and CYBLE-212006-01 Bluetooth Low Energy Module

| RN4020 [1] | EYSGCNZWY [2] | CYBLE-212006-01 [3]
Transmit Power | 7 dBm | 4 dBm | 7.5 dBm
Power Usage (dormant / active) | <900 nA / 16 mA | 600 nA / 5 mA | 1500 nA / 27 mA
Interfaces | AIO, PIO, SPI, UART | I2C, SPI, UART | I2C, SPI, UART
Connection Speed | 1 Mb/s | 1 Mb/s | 1 Mb/s
Size | 11.5 x 19.5 x 2.5 mm | 12.9 x 9.6 x 2.0 mm | 15.0 x 23.0 x 2.0 mm
Weight | 1.2 g | N/A | N/A
| CHOSEN

Of the three bluetooth modules, the RN4020 was chosen to be the best of the three. The EYSGCNZWY had significantly lower power draw comparatively, especially when it was in dormant mode, but this came at the expense of range, as having 4 dBm made it the weakest of the three. This one was also the smallest of the three, but not by such a degree that it overcomes its weaknesses. By contrast, CYBLE-212006-01 stood on the opposite end of the spectrum, trading increased power costs for more range. It had the highest dBm of the three, but it only beat out the RN4020 by .5 dBm. The power difference was more significant, drawing nearly double the RN4020 while dormant, and drawing 9 more mA while operating. While the CYBLE-212006-01 did offer a range advantage, it was determined this advantage was not enough to justify the additional power costs.

For this and all other subsections of section 1.0, provide an analysis of your system component. For your component analysis, compare 2-3 candidate components for each major component choice. Discuss how the design constraints and usage case developed during your functional specification have driven and guided your component choice. Make sure to include which component was chosen for your system. Side-by-side comparison charts are highly appropriate here; be sure to include sources for more information on candidate components.

# 1.1 Analysis of GSM Cell Modems:

For this and all other subsections of section 1.0, provide an analysis of your system component. For your component analysis, compare 2-3 candidate components for each major component choice. Discuss how the design constraints and usage case developed during your functional specification have driven and guided your component choice. Make sure to include which component was chosen for your system. Side-by-side comparison charts are highly appropriate here; be sure to include sources for more information on candidate components.

The GSM cell modem is the heart of our design as it provides both the ability to communicate despite the distance from the user and providing the ability to determine location information through GPS and cell towers. Most communication between user and device will be sent through this device. For our purposes, ease of use and being able to meet any unexpected needs are our main focus for this choice.

In the past, teams in ECE 477 have had trouble having 4G LTE cell modems in their project so because this part is so critical to our project, finding a modem that we can test with and get working early was a key concern. The two parts we were considering both had breakout boards available from Adafruit and had some example code for basic use cases.

| SIMCOM 5320 [4] | SIMCOM 808 [5]
Cell support | Dual-Band UMTS/HSDPA 900/2100MHz Quad-Band GSM/GPRS/EDGE 850/900/1800/1900MHz | Quad-band GSM/GPRS/EDGE 850/900/1800/1900MHz
Networking protocols | TCP/IP FTP/FTPS/HTTP/HTTPS/SMTP/POP3/DNS/MMS | TCP/IP FTP/HTTP/MMS/POP3/SMTP
Embedded Lua support | Yes | No
Interfaces | USB2.0, UART, SIM card, SPI, I2C, Keypad, GPIO, RTC, ADC | USB2.0, UART, SIM card, SPI, I2C, Keypad, GPIO, RTC, ADC
Average current (During a call, Power level = 5, GSM850) | 300 mA | 217 mA
| CHOSEN

When comparing the two the main difference that came into consideration was that one supports only 2G while the other supports both 2G and 3G based on the sim card inserted. While we didn’t anticipate any major need for the speeds of 3G, having the option to switch over if it’s necessary was desired. 2G networks also have less coverage than 3G and may not even be supported in the coming years as they’re phased out so if the device is to be used after this course then having a 3G option may be necessary.

The 5320 also has more software support making it more flexible than the 808. The 5320 offers the ability to run off of embedded Lua scripts which could allow us to speed up our development through using a high level language. It also offers more modern support for networking protocols in the situation that we find it necessary to use GPRS to communicate at all.

The main downside behind the 5320 is that by offering more flexibility and options it ends up costing more in power. Power is one of our biggest concerns for this project as this device is portable but doesn’t interact directly with the user that often. After careful consideration, we decided that because two of our PSSCs rely on our modem, flexibility would hold as more important over power consumption.

# 1.1 Analysis of LCDs:

LCD is the method which the Track-on-track device uses to communicate with the user when the user is in possession of the device. This is useful because it gives the user the ability to interact with the device directly, without having to use a secondary device like a phone. This is also useful for pairing the device during first time setup, and for displaying information directly to the user, such as battery life.

One constraint of the LCD is size and weight. The LCD that is chosen must be small enough to fit into the design without taking up an excess of space. In addition, it must be lightweight. This is because it will be carried along with the rest of the device, and while having a large LCD to display information to the user would be desirable, it is more important for it to be lightweight and of a relatively small size.

Another constraint is power consumption. As will all other components of our design, the LCD must be more conservative with its power. This may mean the design will end up incorporating a less well-lit, uglier LCD if it ends up being more efficient. Although the LCD will spend much of its time off, only being turned on when the user attempts to use the physical interface, this is still considered a priority due to the mobile nature of the project.

| EA DOGS104W-A[8] (https://www.mouser.com/ds/2/127/dogs104e-553061.pdf) | EA DIPS082-HNLED[9] (https://www.mouser.com/ds/2/127/dips082e-274871.pdf) | NHD-0208AZ-FL-YBW[10] (https://www.mouser.com/ds/2/291/NHD-0208AZ-FL-YBW-2946.pdf)
Lines x Characters | 4x10 | 2x8 | 2x8
Power Usage | 1.45 mW | 5.4mW | 7.2mW
Size | 36mm x 25.4mm x 2mm | 40mm x 20mm x 5.01mm | 40mm x 35.4mm x 13mm
Interfaces | SPI, I2C | 8-bit Data Bus | 8-bit Data Bus
backlight | no backlight or seperate LED backlight | optional | optional
| CHOSEN

For the selection of the LCD display. Three LCDs are chosen. The reason for these three candidates is that these displays have reflective display mode, which needs no backlighting. Considering our power consumption constraints which is a very essential constraint for our project, backlighting is as important as the power we can save without it. On the other hand, these candidates are the smallest while at the same time can provide enough character displays to display battery life, signal strength, and the interaction menus for users. When it comes to interfaces, it is not important since the control of LCD display is easy either with general purpose I/O pins or SPI, I2C interfaces.

The EA DOGS104W-A LCD display is the smallest and thinnest display among them which can help make our project take less space. It consumes the least power when operated without backlight. It also has more capacity of characters. Moreover, with easy-to-use SPI interface, it can be connected to the SPI module of the microprocessor.

# 1.1 Analysis of Microcontrollers:

The microcontroller is the most important single aspect of the design, as it is the component which will regulate the communications coming from and going to the bluetooth, the GSM cell modem, and the physical interface.The microcontroller is also responsible for holding user settings such as turning on and off the audio alarm, and using the settings in its function. In addition, the microcontroller is responsible for encoding and decoding messages to and from the various peripherals.

Power consumption is the primary constraint for the microcontroller. The microcontroller may be able to spend much of its time in a partially dormant mode, but it will have to constantly check for interrupts coming to it through the cell modem. Thus, the microcontroller will constantly be burning through power whenever the device is on. Another factor in memory consumption is the type of memory. Flash memory is the standard for non-volatile storage, but in recent years FRAM has gained popularity. FRAM is a non-volatile storage which is prized for its low power consumption, making it something to look for in a microcontroller.

The memory size and calculation speed of the microcontroller will also come into play when deciding which microcontroller is right for this project. Memory is not a major concern, as the bulk of what will need to be stored will be the program itself. Therefore, only a few Kb of non-volatile storage should be more than enough for Track-on-track. Speed, while a notable concern, is not the most important aspect of the design. Because much of the Track-on-track device’s time will be spent waiting on information from much slower transmission protocols, an incredibly fast microcontroller may not be able to utilize its full potential. Speed, however, is still an important factor in making sure transmissions are taken in, decoded, and responded to as quickly as possible, meaning that speed will still weigh heavily in the decision.

| MSP430F2618 [6] | MSP430FR69891 [7]
Non-Volatile Storage | 116 kB + 256 B Flash | 128 kB FRAM
RAM | 8 kB | 2 kB
Power | .460 mA @ 1 MHz | .375 mA @ 1 MHz
Number of UART | 2 | 2
Number of SPI | 3 | 4
Max Clock Frequency | 12 MHz | 8 MHz
Pin Count | 64 | 83
| | CHOSEN

For the microcontroller selection, two microcontrollers from the MSP430 family were chosen. This is because the MSP430’s are RISK processors, and the reduced instruction set is likely to reduce the complexity and the power consumption of the device. In addition, MSP430 is a family which is known for producing excellent low power microcontrollers, and low power is one of the main goals for the microcontroller of this device. From the family, two were selected as likely candidates. The MSP430F2618 offered greater amounts of RAM and a higher max clock frequency, which could potentially lead to much higher performance. However, the MSP430FR69891 had an additional SPI module and much more pins. The biggest draw by far however, was the fact that the MSP430FR69891 drew almost .1 mA less current than the MSP430F2618 did at 1 MHz. Because power consumption is the number one concern for Track-on-track, MSP430FR69891 was selected.

For this and all other subsections of section 1.0, provide an analysis of your system component. For your component analysis, compare 2-3 candidate components for each major component choice. Discuss how the design constraints and usage case developed during your functional specification have driven and guided your component choice. Make sure to include which component was chosen for your system. Side-by-side comparison charts are highly appropriated here; be sure to include sources for more information on candidate components.

# 2.0 Sources Cited:

[1] Microchip Technology Inc., “RN4020-V/RM120 Datasheet,” Mouser. [Online]. Available: https://www.mouser.com/ds/2/268/50002279B-846406.pdf [Accessed: 24-Jan-2018].

[2] Taiyo Yuden, “EYSGCNZWY Datasheet,” Mouser, 09-Aug-2016. [Online]. Available: https://www.mouser.com/ds/2/396/TY_BLE_EYSGCNZ_DataReport_V1_3_20160809E-1090119.pdf [Accessed: 25-Jan-2018].

[3] Cypress Semiconductor, “CYBLE-212006-01 Datasheet,” Mouser, 22-Jun-2017. [Online]. Available: https://www.mouser.com/ds/2/100/002-15631_CYBLE-2X20XX-X1_EZ-BLE_PRoC_XR_Module_Da-1102459.pdf [Accessed: 25-Jan-2018].

[4] “SIM5320,” SIM5320 | SIMCom | smart machines, smart decision. [Online]. Available: http://simcom.ee/modules/wcdma-hspa/sim5320/. [Accessed: 25-Jan-2018].

[5] “SIM808,” SIM808 | SIMCom | smart machines, smart decision. [Online]. Available: http://simcom.ee/modules/gsm-gprs-gnss/sim808/. [Accessed: 25-Jan-2018].

[6] Texas Instruments, “MIXED SIGNAL MICROCONTROLLER DATASHEET,” ti, 01-Nov-2012. [Online]. Available: http://www.ti.com/lit/ds/symlink/msp430f2618.pdf [Accessed: 25-Jan-2018].

[7] Texas Instruments, “MSP430FR698x(1), MSP430FR598x(1) Mixed-Signal Microcontrollers (Rev. C),” ti. [Online]. Available: http://www.ti.com/product/MSP430FR69891/datasheet/abstract#SLAS7895249 [Accessed: 25-Jan-2018].

[8] Mouser.com. (2017). EA DOGS104-A. [online] Available at: https://www.mouser.com/ds/2/127/dogs104e-553061.pdf [Accessed 26 Jan. 2018].

# Throughout this and other papers, use of the IEEE citation style should be used. Use of embedded hyperlinks for all web-based sources is required. A reference to the IEEE citation style format is provided here (http://www.ieee.org/documents/ieeecitationref.pdf).

[9] Mouser.com. (2017). EA DOGS104-A. [online] Available at: https://www.mouser.com/ds/2/127/dips082e-274871.pdf [Accessed 26 Jan. 2018].

[10] Mouser.com. (2017). EA DOGS104-A. [online] Available at: https://www.mouser.com/ds/2/291/NHD-0208AZ-FL-YBW-2946.pdf [Accessed 26 Jan. 2018].

https://engineering.purdue.edu/ece477 Page of

ECE 477: Digital Systems Senior Design Last Modified: 03-03-2015

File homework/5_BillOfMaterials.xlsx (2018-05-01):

ECE477 Bill of Materials v1.0
Year: 2018 |  | Semester: Spring |  |  | Project Name: Track-on-track
Author: | Nick Geirland | Nathan McNally | Yunsheng Li | Aaron Kaiser
Created: 1/31/2018
Last Modified: 1/31/2018
Project_Component |  |  |  |  |  |  |  | Qty:
Description | ID | Qty | Value | Package | Manufacturer | Mfg. Part # | Supplier | Supplier Part #
BATTERY LITHIUM 3.7V 6AH |  | 1 | 6 Ah | Off-Board | SparkFun Electronics | PRT-13856 | digikey | 1568-1494-ND
Microcontroller MSP430FR69891 |  | 1 | - | LQFP | Texas Instruments |  | Mouser Electronics
LCD |  | 1 | - | Tray | Electronic Assembly | EA DOGS104W-A | Mouser Electronics | 790-EADOGS104W-A
2.5v buck/boost regulator |  | 1 | 2.5 V | SOT-23-6 | Texas Instruments | REG710NA-2.5/250 | Mouser Electronics | 595-REG710NA-2.5/250
3.3v buck/boost regulator |  | 1 | 3.3 V | SOT-23-6 | Texas Instruments | REG710NA-3.3/3K | Mouser Electronics | 595-REG710NA-3.3/3K
Buzzer |  | 1 | 90 dB | Through Hole | CUI | CPT-2272C-200 | Mouser Electronics | 490-CPT-2272C-200
Lithium Ion charging IC |  | 1 | - | SOT-23 | Microchip | MCP73831T-2ACI/OT | Mouser Electronics | 579-MCP73831T-2ACIOT
GSM Cell Modem |  | 1 | - | SMT | SIMCOM | 53020A | Ebay | -
Bluetooth Module |  | 1 | - | SMT | Microchip Technology | RN4020-V/RM | Mouser Electronics | 765-RN4020-V/RM
Resistor |  | 1 | 2 kohm | 0805 | ROHM Semiconductor | ESR10EZPF2001 | Mouser Electronics | 755-ESR10EZPF2001
Decoupling Capacitor |  | 5 | .1 uF | 1206 | KEMET | C1206X104J3JACAUTO | Mouser Electronics | 80-C1206X104J3JAUTO
Electrolytic Capacitor |  | 2 | 100 uF | Through Hole | Nichicon | UKL2A101KHD | Mouser Electronics | 647-UKL2A101KHD
Voltage regulator pump capacitor |  | 2 | .22 uF | 1206 | KEMET | C1206C224J3JACTU | Mouser Electronics | 80-C1206C224J3J
Voltage regulator inout capacitor |  | 4 | 2.2 uF | 1206 | KEMET | C1206C225J8RACAUTO | Mouser Electronics | 80-C1206C225J8RAUTO

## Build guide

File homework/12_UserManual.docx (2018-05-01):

# User Manual

# Year: 2018 Semester: Spring Team: 16 Project: Track-on-track

# Creation Date: 4/11/2018 Last Modified: April 12, 2015

# Member 1: Nick Geirland Email: ngeirlan@purdue.edu

# Member 2: Nathan McNally Email: nmcnall@purdue.edu

# Member 3: Yunsheng Li Email: li1436@purdue.edu

# Member 4: Aaron Kaiser Email: kaiser20@purdue.edu

# Assignment Evaluation:

Item | Score (0-5) | Weight | Points | Notes

Assignment-Specific Items
Product Description | | x1
Product Illustration | | x2
Setup Instructions | | x3
Usage Instructions | | x3
Troubleshooting Instructions | | x3

Writing-Specific Items
Spelling and Grammar | | x2
Formatting and Citations | | x1
Figures and Graphs | | x2
Technical Writing Style | | x3
Total Score

# 5: Excellent 4: Good 3: Acceptable 2: Poor 1: Very Poor 0: Not attempted

# Comments:

# 1.0 Product Description

Losing a bag or having it stolen can be a troublesome experience for anyone who carries personal belongings or valuables with them. Tracing back your steps to find something is an arduous task, and often times can come up empty. The Track-on-track device was designed to help anyone with a bag or luggage find their item if it was lost or stolen. The device is designed as a box, which can be placed in the bag that the customer wants to know the location of, where it will stay for up to 2 months without charge. It includes buttons which can be used to configure settings, and an LCD screen which can relay information. The device can be contacted at long range via a text message, where it will send back a message with its GPS coordinates, as long as it is receiving signal. It can also use bluetooth at close range to approximate distance to the user. This product also includes an app which makes communicating with the device simple, and even includes a display which shows where the device is on Google Maps.

# 2.0 Product Illustrations

Complete System and Features:


# 3.0 Setup Instructions

# 1. Charge the battery by plugging the MicroUSB cable into the charging port on the side of device.

2. Download the phone app for the device from our apk if you have android.
3. Set the phone number and name for the device in the app’s settings.
4. The app will ask for you to setup a password with the device or if you’re using SMS then text “SetPass:<password>”. If the device hasn’t already been setup then commands shouldn’t require a password yet.
5. Either open the app to test bluetooth connection, location functionality, and the buzzer or text the device to test just the location functionality.
6. Once it is charged, put the device into the item to be tracked.

# 4.0 Usage Instructions

# For long-range tracking:

1. On android:
  a. Open the app and tap on the middle track button () which will requests the device’s location.
  b. Wait for the device to respond with a set of coordinates.
  c. The map will automatically update the device’s marker with the new set of coordinates.
2. On SMS:
  a. Text the device “<password>: LocReq”.
  b. Wait for the device to respond with a set of coordinates.

For short-range tracking (only available through app):

1. Open the app and tap on the left Bluetooth button () which will take you to the Bluetooth screen.
2. If the device has not yet been paired, tap the pair button to sync a new device.
3. If the device has been paired and is within range, the app and device will automatically pair when the app is open.
4. The signal strength indicator will display the connection strength between the device and the app.
5. As you move further or closer to the device, the signal strength indicator will update.
6. A higher strength signal indicates the device is closer in proximity, while a lower strength signal indicates the device is farther in proximity.
7. The device’s buzzer can also be activated through Bluetooth.
  a. Tapping on the buzzer button () will activate the device’s buzzer until the button is released.

For navigation in the device menu:

1. Switch the Enable Switch to On position.
2. Use the top push button to go up in the menu
3. Use the bottom push button to go down in the menu
4. Use the middle push button to make a selection

# 5.0 Troubleshooting Instructions

Problem | Potential Solutions
The device’s LCD doesn’t show anything | - The device may need to be charged. See setup instructions - If charging doesn’t solve the problem, please contact Track-on-Track support team at the number below
App cannot connect with device via bluetooth | - The device may be out of range for bluetooth connection. Check map in the phone app to confirm the GPS location of device. - If the device is in close range but the problem persists, close the app and try again. - Unpair the Bluetooth connection between the phone app and device, and then attempt to pair them again. - If above steps don’t solve the problem, please contact Track-on-Track support team at the number below
The device’s location doesn’t show up in the app | - It could be the battery has died in which case you’ll have to get to the device and recharge - The device may have no or low cell reception. Move the device to a new location and try again. - Wait a few minutes and try again. It could be taking a while for the communications to go through.
The device’s location doesn’t update in the app when a new set of coordinates is received | - Verify and update (if necessary) the device’s phone number in the app’s settings to correctly match the device’s phone number
The device doesn’t respond with a new set of coordinates when tracking is initiated | - Verify and update (if necessary) the device’s password in the app’s settings to correctly match the device’s password

# We are sorry you are experiencing trouble with your Track-on-Track!

24/7 Customer support: 1-999-999-9876

https://engineering.purdue.edu/ece477 Page of

ECE 477: Digital Systems Senior Design Last Modified: 03-03-2015

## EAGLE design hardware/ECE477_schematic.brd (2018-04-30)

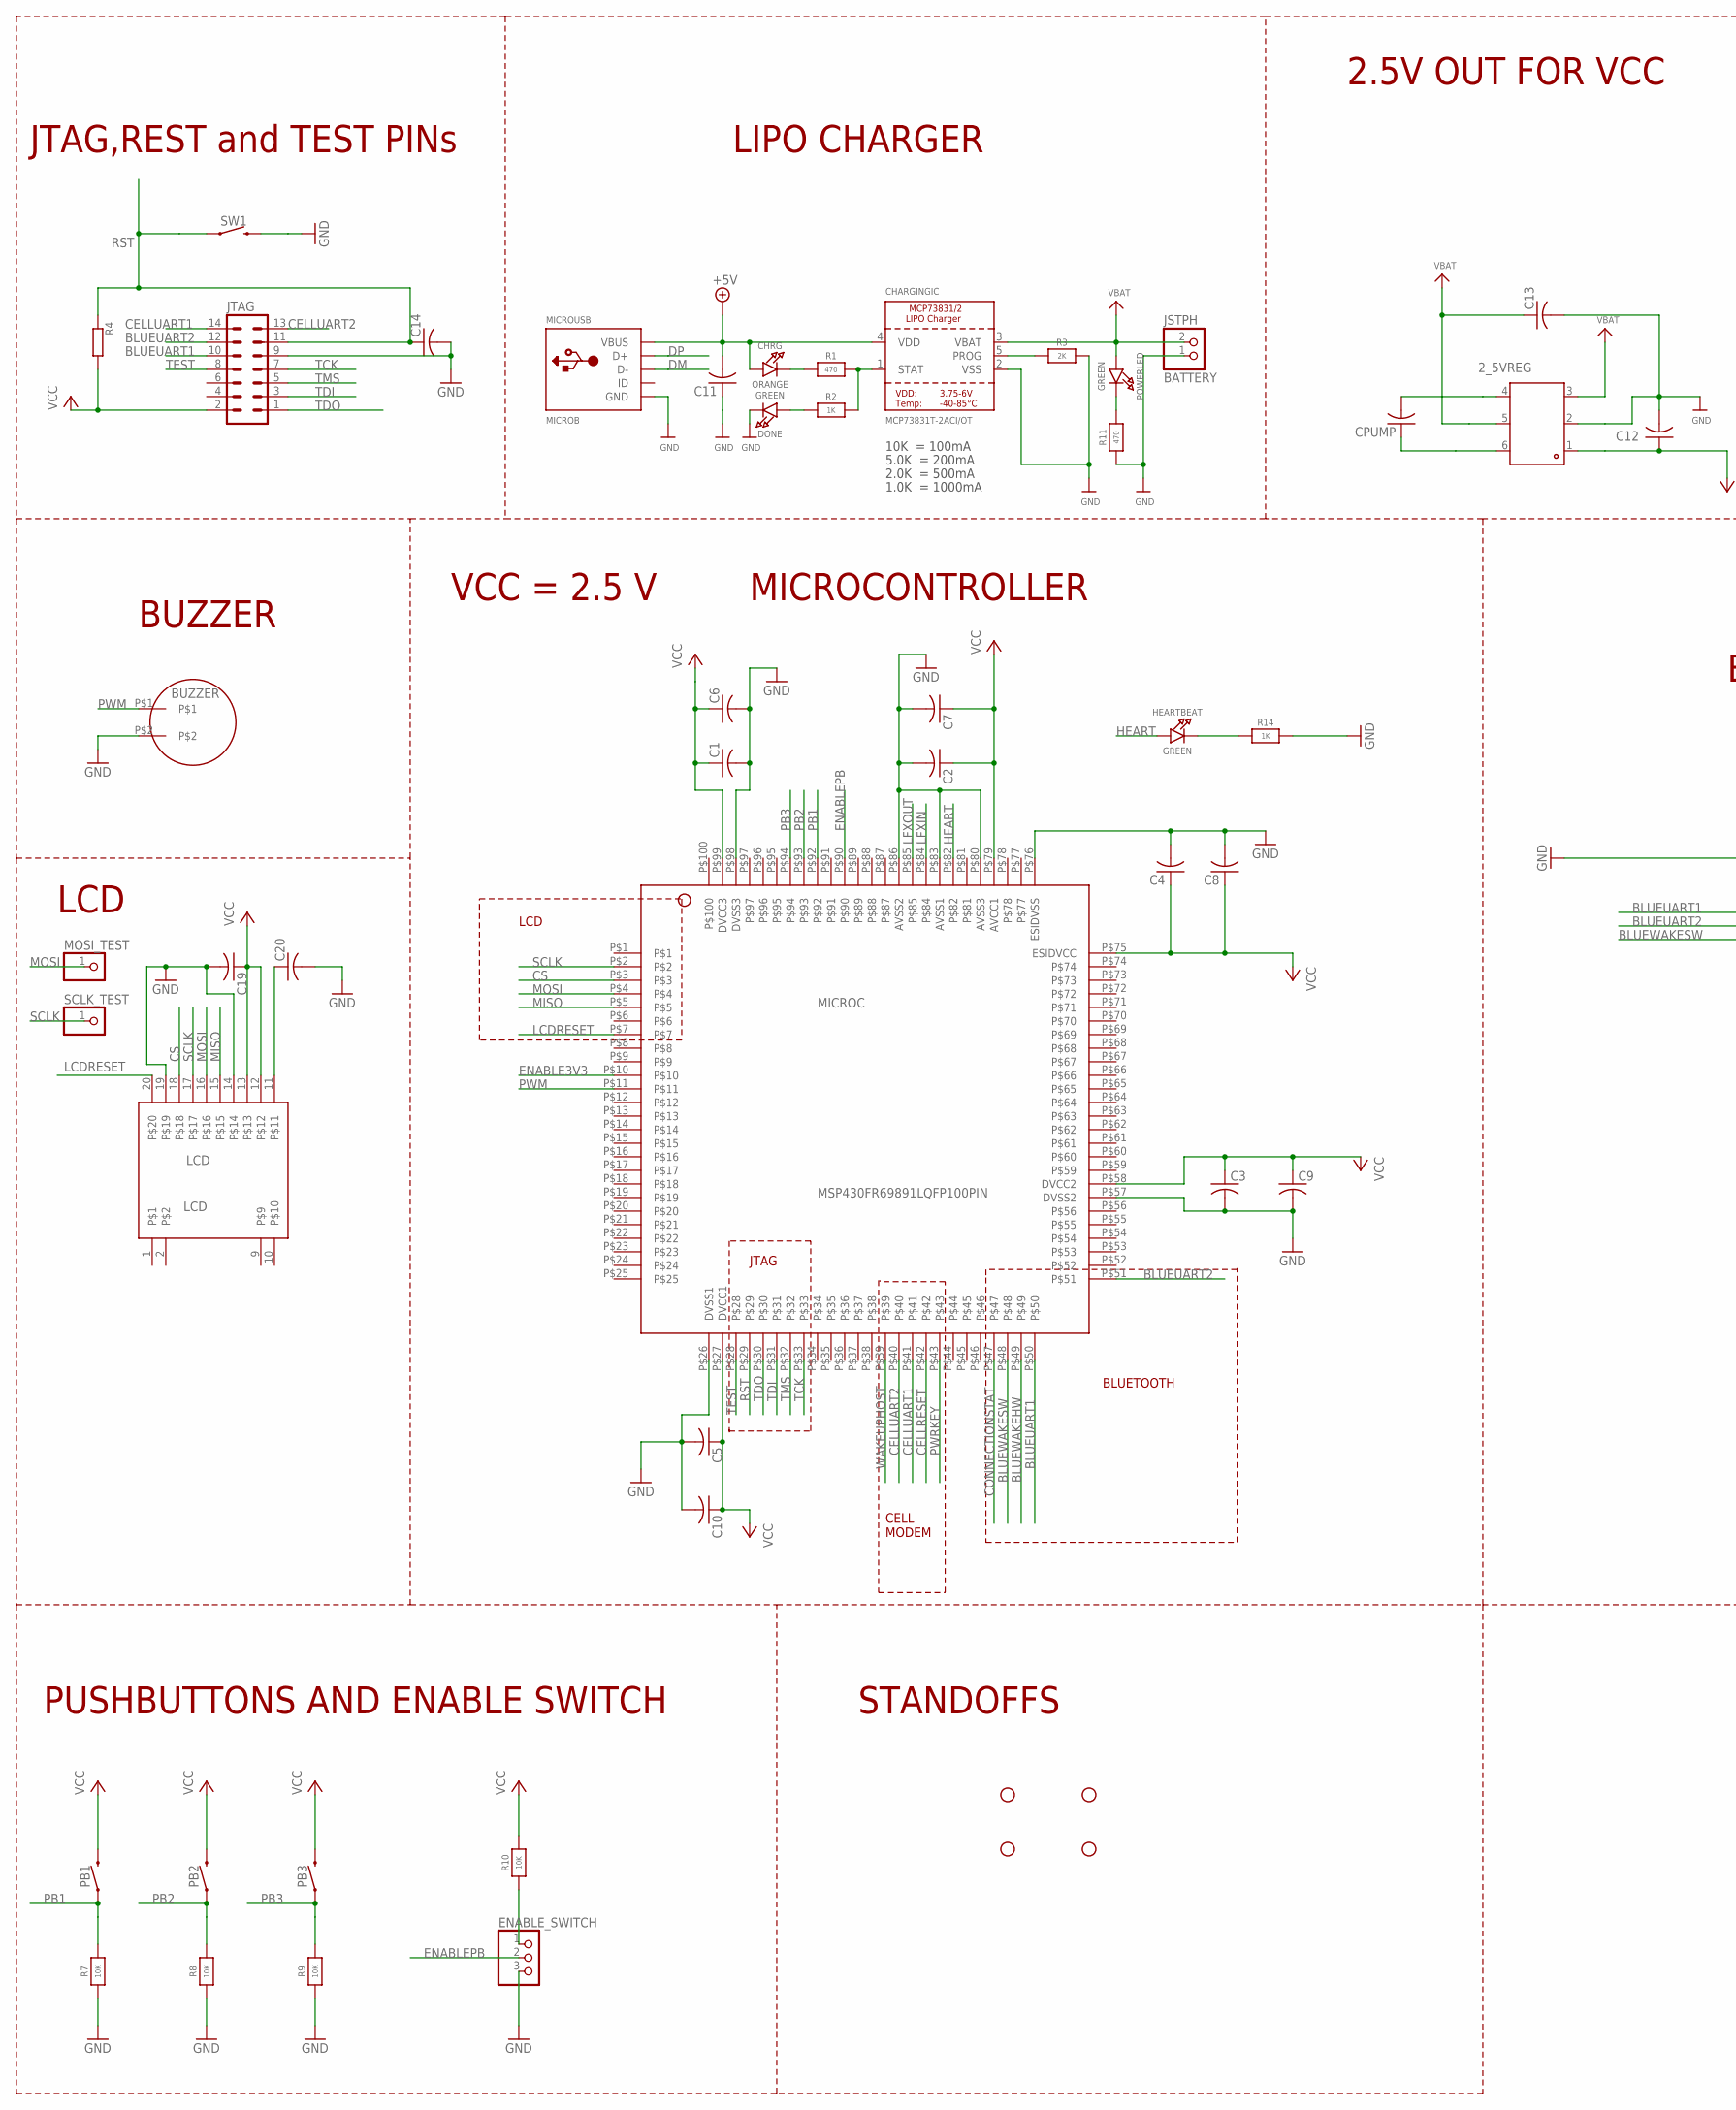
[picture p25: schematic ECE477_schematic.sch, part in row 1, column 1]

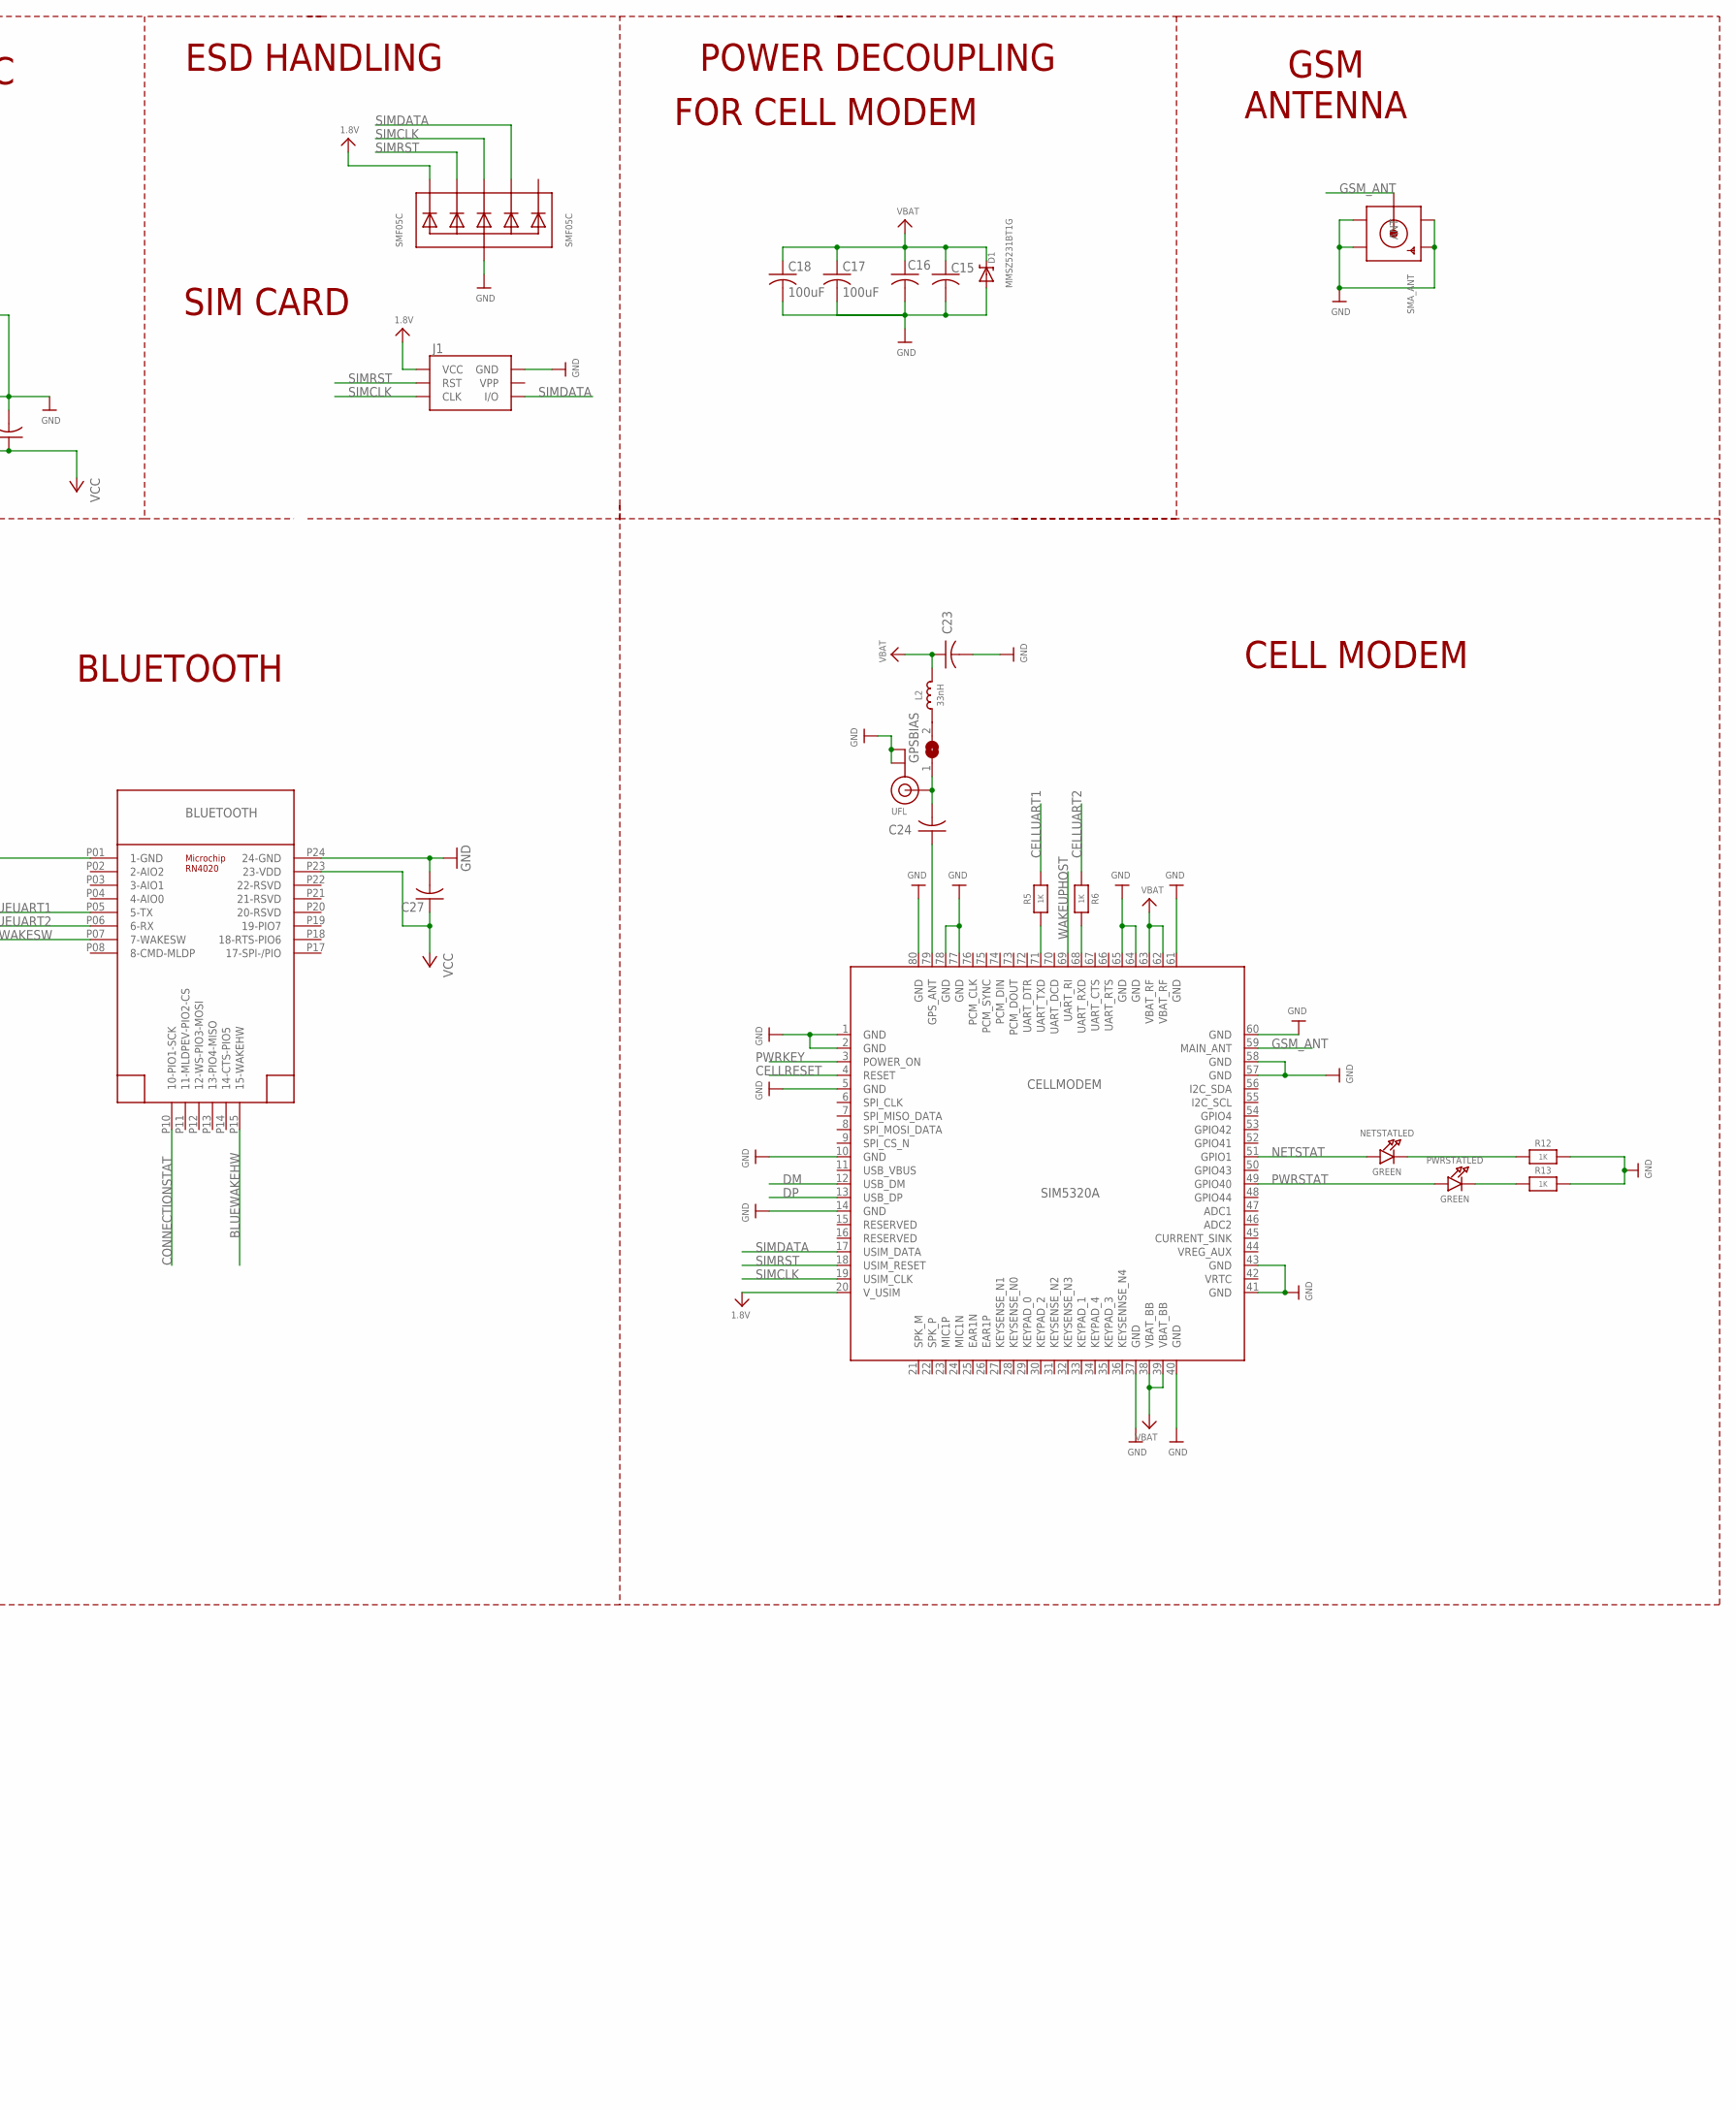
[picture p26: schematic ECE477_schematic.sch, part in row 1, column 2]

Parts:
2_5VREG: 2_5VREG; REG710NASOC6
BATTERY: JSTPH; JSTPH2
BLUETOOTH: RN4020; RN4020SMD
BUZZER: BUZZER; BUZZERTHROUGHHOLE
C1, C2, C3, C4, C5, C6, C7, C8, C9, C10, C11, C12, C13, C14, C15, C16, C19, C20, C23, C24, C27: C-USC1206; C1206
C17, C18: 100uF; C1210
CELLMODEM: SIM5320A; MICROBUILDER_SIM5320
CHARGINGIC: MCP73831T-2ACI/OT; SOT23-5
CHRG: ORANGE; CHIPLED_0805_NOOUTLINE
CPUMP: C-USC1206; C1206
D1: MMSZ5231BT1G; SOD-123
DONE: GREEN; CHIPLED_0805_NOOUTLINE
ENABLE_SWITCH: PINHD-1X3; 1X03
GPSBIAS: SOLDERJUMPER; SOLDERJUMPER_ARROW_NOPASTE
H1, H2, H3, H4: STAND-OFF
HEARTBEAT: GREEN; CHIPLED_0805_NOOUTLINE
J1: SIMHOLDERSIM; SIMHOLDER
JTAG: CON-ML_ML14
L2: 33nH; _0805MP
LCD: LCD; LCDTHROUGHHOLE
MICROC: MSP430FR69891LQFP100PIN; MSP430FR69891
MICROUSB: MICROB; ZX62DB5PA8(30)
MOSI_TEST: PINHD-1X1; 1X01
NETSTATLED: GREEN; CHIPLED_0805_NOOUTLINE
PB1, PB2, PB3: MOMENTARY-SWITCH-SPST-PTH-6.0MM; TACTILE_SWITCH_PTH_6.0MM
POWERLED: GREEN; CHIPLED_0805_NOOUTLINE
PWRSTATLED: GREEN; CHIPLED_0805_NOOUTLINE
R1, R11: 470; 0805-NO
R2, R5, R6, R12, R13, R14: 1K; 0805-NO
R3: 2K; 0805-NO
R4: SMD_R_0805; SMD_0805
R7, R8, R9, R10: 10K; 0805-NO
SCLK_TEST: PINHD-1X1; 1X01
SMA_ANT: MICROBUILDER_SMACONNECTOR_EDGE; MICROBUILDER_SMA_EDGELAUNCH
SMF05C: SMF05C; SOT363
SW1: MOMENTARY-SWITCH-SPST-PTH-6.0MM; TACTILE_SWITCH_PTH_6.0MM
UFL: MICROBUILDER_ANTENNA_U.FL; MICROBUILDER_U.FL

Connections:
1.8V: CELLMODEM.20 (V_USIM), J1.C1 (VCC), SMF05C.1 (C1)
+5V: C11.2, CHARGINGIC.4 (VDD), CHRG.A, MICROUSB.+5V (VBUS)
BLUEUART1: BLUETOOTH.P05 (5-TX), JTAG.10, MICROC.P$50
BLUEUART2: BLUETOOTH.P06 (6-RX), JTAG.12, MICROC.P$51
BLUEWAKEHW: BLUETOOTH.P15 (15-WAKEHW), MICROC.P$49
BLUEWAKESW: BLUETOOTH.P07 (7-WAKESW), MICROC.P$48
CELLRESET: CELLMODEM.4 (RESET), MICROC.P$42
CELLUART1: JTAG.14, MICROC.P$41, R5.2
CELLUART2: JTAG.13, MICROC.P$40, R6.2
CONNECTIONSTAT: BLUETOOTH.P10 (10-PIO1-SCK), MICROC.P$47
CS: LCD.18, MICROC.P$3
DM: CELLMODEM.12 (USB_DM), MICROUSB.D-
DP: CELLMODEM.13 (USB_DP), MICROUSB.D+
ENABLE3V3: MICROC.P$10
ENABLEPB: ENABLE_SWITCH.2, MICROC.P$90
GND: 2_5VREG.2, BATTERY.1, BLUETOOTH.P01 (1-GND), BLUETOOTH.P24 (24-GND), BUZZER.P$2, C1.2, C2.2, C3.2, C4.2, C5.2, C6.2, C7.2, C8.2, C9.2, C10.2, C11.1, C12.2, C13.2, C14.2, C15.2, C16.2, C17.2, C18.2, C19.2, C20.2, C23.2, C27.2, CELLMODEM.1 (GND), CELLMODEM.2 (GND), CELLMODEM.5 (GND), CELLMODEM.10 (GND), CELLMODEM.14 (GND), CELLMODEM.37 (GND), CELLMODEM.40 (GND), CELLMODEM.41 (GND), CELLMODEM.43 (GND), CELLMODEM.57 (GND), CELLMODEM.58 (GND), CELLMODEM.60 (GND), CELLMODEM.61 (GND), CELLMODEM.64 (GND), CELLMODEM.65 (GND), CELLMODEM.77 (GND), CELLMODEM.78 (GND), CELLMODEM.80 (GND), CHARGINGIC.2 (VSS), D1.A, DONE.C, ENABLE_SWITCH.3, J1.C5 (GND), JTAG.9, LCD.14, LCD.19, MICROC.P$26 (DVSS1), MICROC.P$57 (DVSS2), MICROC.P$76 (ESIDVSS), MICROC.P$80 (AVSS3), MICROC.P$83 (AVSS1), MICROC.P$86 (AVSS2), MICROC.P$98 (DVSS3), MICROUSB.GND, R3.2, R7.1, R8.1, R9.1, R11.1, R12.2, R13.2, R14.2, SMA_ANT.GND@1 (GND4), SMA_ANT.GND@2 (GND3), SMA_ANT.GND@3 (GND2), SMA_ANT.GND@4 (GND1), SMF05C.2 (A), SW1.3 (2), UFL.1 (GND), UFL.2 (GND)
GSM_ANT: CELLMODEM.59 (MAIN_ANT), SMA_ANT.P (ANT)
HEART: HEARTBEAT.A, MICROC.P$82
LCDRESET: LCD.20, MICROC.P$7
LFXIN: MICROC.P$84
LFXOUT: MICROC.P$85
MISO: LCD.15, MICROC.P$5
MOSI: LCD.16, MICROC.P$4, MOSI_TEST.1
unnamed: CHRG.C, R1.1
unnamed: CHARGINGIC.1 (STAT), R1.2, R2.2
unnamed: C20.1, LCD.11
unnamed: 2_5VREG.4, CPUMP.2
unnamed: CHARGINGIC.5 (PROG), R3.1
unnamed: DONE.A, R2.1
unnamed: 2_5VREG.6, CPUMP.1
unnamed: C24.1, CELLMODEM.79 (GPS_ANT)
unnamed: C24.2, GPSBIAS.1, UFL.3 (SIGNAL)
unnamed: CELLMODEM.71 (UART_TXD), R5.1
unnamed: CELLMODEM.68 (UART_RXD), R6.1
unnamed: POWERLED.C, R11.2
unnamed: NETSTATLED.C, R12.1
unnamed: ENABLE_SWITCH.1, R10.1
unnamed: PWRSTATLED.C, R13.1
unnamed: GPSBIAS.2, L2.1
unnamed: HEARTBEAT.C, R14.1
NETSTAT: CELLMODEM.51 (GPIO1), NETSTATLED.A
PB1: MICROC.P$92, PB1.1, R7.2
PB2: MICROC.P$93, PB2.1, R8.2
PB3: MICROC.P$94, PB3.1, R9.2
PWM: BUZZER.P$1, MICROC.P$11
PWRKEY: CELLMODEM.3 (POWER_ON), MICROC.P$43
PWRSTAT: CELLMODEM.49 (GPIO40), PWRSTATLED.A
RST: C14.1, JTAG.11, MICROC.P$29, R4.1, SW1.1
SCLK: LCD.17, MICROC.P$2, SCLK_TEST.1
SIMCLK: CELLMODEM.19 (USIM_CLK), J1.C3 (CLK), SMF05C.4 (C3)
SIMDATA: CELLMODEM.17 (USIM_DATA), J1.C7 (I/O), SMF05C.5 (C4)
SIMRST: CELLMODEM.18 (USIM_RESET), J1.C2 (RST), SMF05C.3 (C2)
TCK: JTAG.7, MICROC.P$33
TDI: JTAG.3, MICROC.P$31
TDO: JTAG.1, MICROC.P$30
TEST: JTAG.8, MICROC.P$28
TMS: JTAG.5, MICROC.P$32
VBAT: 2_5VREG.3, 2_5VREG.5, BATTERY.2, C13.1, C15.1, C16.1, C17.1, C18.1, C23.1, CELLMODEM.38 (VBAT_BB), CELLMODEM.39 (VBAT_BB), CELLMODEM.62 (VBAT_RF), CELLMODEM.63 (VBAT_RF), CHARGINGIC.3 (VBAT), D1.C, L2.2, POWERLED.A
VCC: 2_5VREG.1, BLUETOOTH.P23 (23-VDD), C1.1, C2.1, C3.1, C4.1, C5.1, C6.1, C7.1, C8.1, C9.1, C10.1, C12.1, C19.1, C27.1, JTAG.2, LCD.12, LCD.13, MICROC.P$27 (DVCC1), MICROC.P$58 (DVCC2), MICROC.P$75 (ESIDVCC), MICROC.P$79 (AVCC1), MICROC.P$99 (DVCC3), PB1.3 (2), PB2.3 (2), PB3.3 (2), R4.2, R10.2
WAKEUPHOST: CELLMODEM.69 (UART_RI), MICROC.P$39

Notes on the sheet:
10K = 100mA
5.0K = 200mA
2.0K = 500mA
1.0K = 1000mA
LIPO CHARGER
2.5V OUT FOR VCC
JTAG,REST and TEST PINs
SIM CARD
POWER DECOUPLING
GSM ANTENNA
LCD
ESD HANDLING
BLUETOOTH
JTAG
CELL MODEM
CELL MODEM
BUZZER
MICROCONTROLLER
PUSHBUTTONS AND ENABLE SWITCH
VCC = 2.5 V
STANDOFFS
FOR CELL MODEM

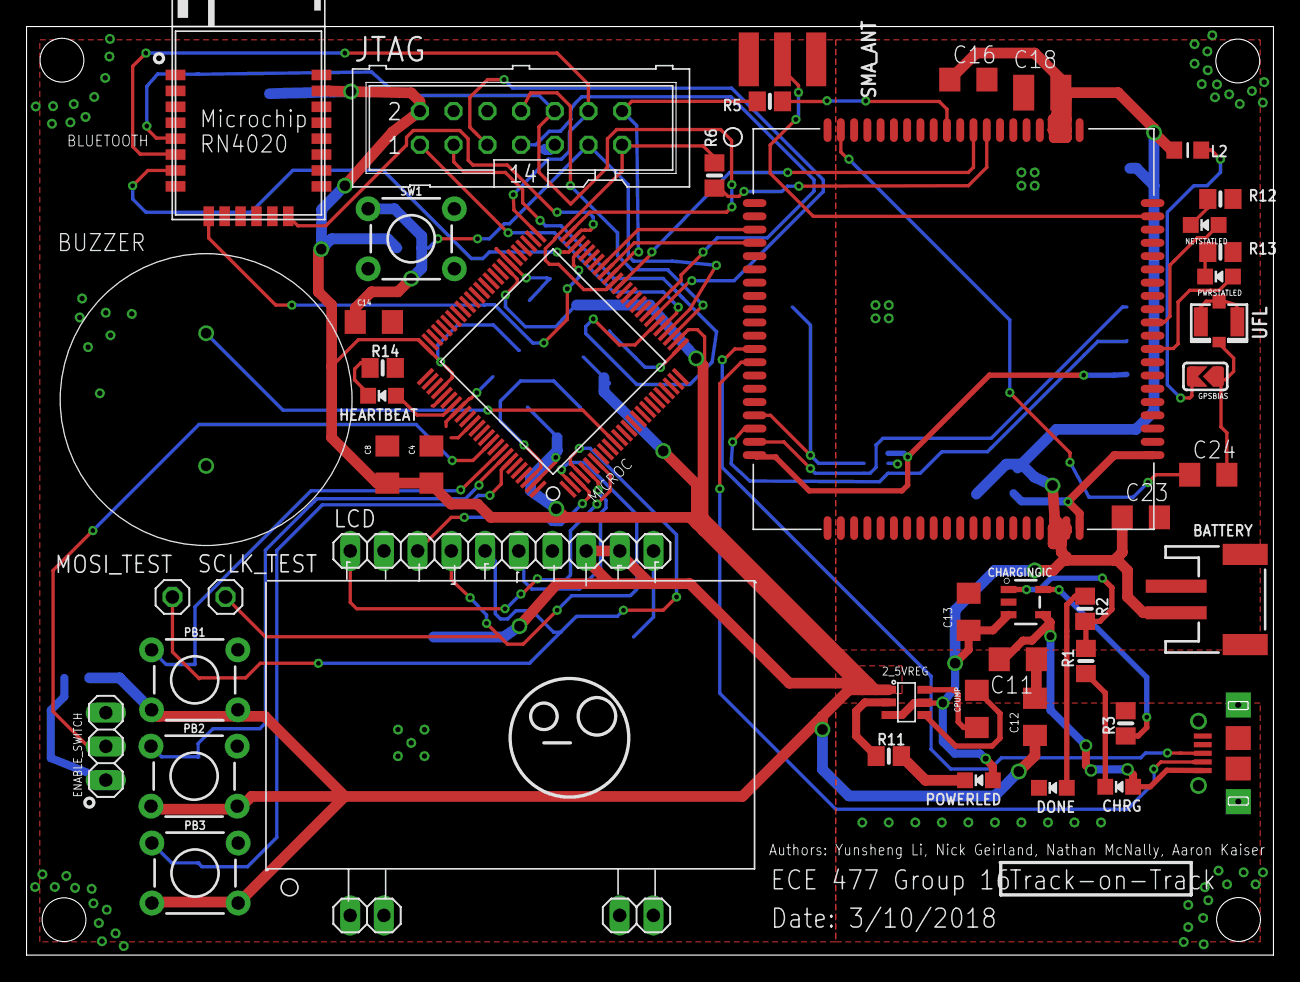
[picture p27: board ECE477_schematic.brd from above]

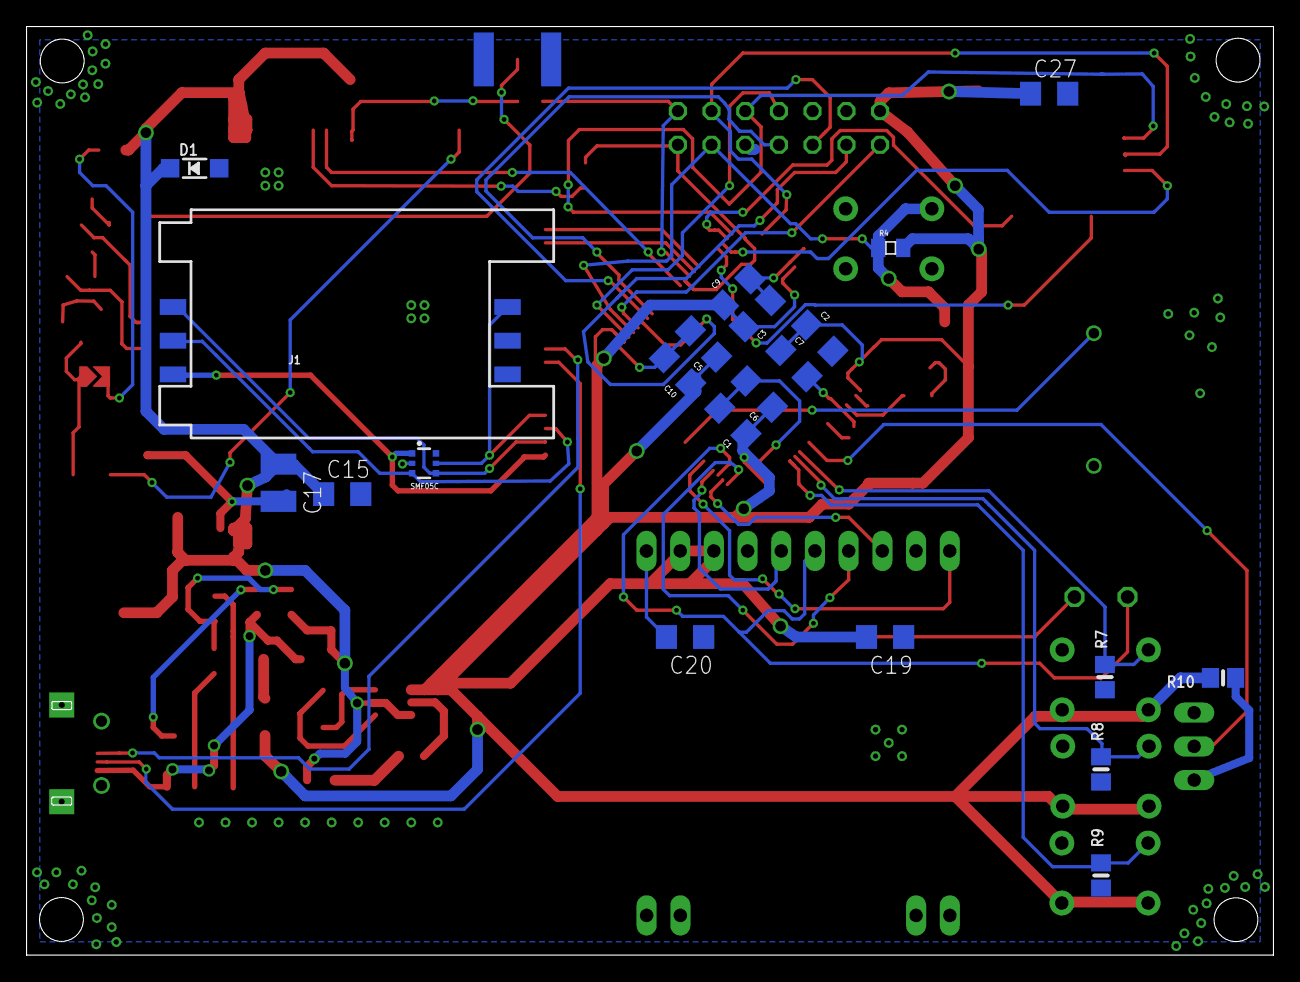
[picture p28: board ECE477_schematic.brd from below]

Board: 2 copper layers, 94.0 x 70.0 mm, 72 parts (21 on the bottom side), 57 nets.

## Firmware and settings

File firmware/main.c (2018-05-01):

#include <msp430.h>
#include "gsm_uart.h"
#include "bluart.h"
#include "system.h"
#include "lcd.h"

void init() {
    // These were in examples and seem important
    WDTCTL = WDTPW | WDTHOLD;               // Stop watchdog timer
    PM5CTL0 &= ~LOCKLPM5;                   // Disable the GPIO power-on default high-impedance mode
                                            // to activate previously configured port settings
    // General init
    PJDIR |= 0x40;
    PJOUT |= 0x40;
    clock_init();

    // Subsystem init
    gsm_init();
    blue_init();
    PJOUT |= 0x40;
    lcd_init();
    PJOUT &= ~0x40;
}

void main(void) {
    int oldsmscount;
    int newsmscount;
    int oldbluerecpos;
    int pos, newpos, i;
    char sender[16];
    char location[26];

    init();

    oldbluerecpos = bluerecpos;
    gsm_delay();
    PJOUT |= 0x40;
    oldsmscount = gsm_sms_count();
    PJOUT &= ~0x40;

    /*TB0CTL = 0x210;
    //TB0R = 0x100;
    TB0CCR0 = 0x50;
    TB0CCR1 = 0x100;
    TB0CCTL1 |= 0xa0;
    P6DIR |= 0x10;
    P6SEL0 |= 0x10;*/

    for(;;) {
        gsm_command("at+csq\r\n", 1);
        gsm_command("at+cgpsinfo\r\n", 1);
        pos = gsmrecpos;
        gsm_command("at+cassistloc=1\r\n", 0);
        //pos = gsmrecpos;
        //while(gsmrecpos == pos);
        while(!gsm_rec_check("+CASS", pos, gsmrecpos));
        newsmscount = gsm_sms_count();
        if (newsmscount > oldsmscount) {
            pos = gsmrecpos;
            gsm_read_sms(oldsmscount);
            newpos = gsmrecpos;
            pos = gsm_rec_check("READ\",\"+", pos, newpos);
            for (i = 0; i < 11; i++) {
                sender[i] = gsmreceived[(pos + 7 + i) & GSM_RECPOS_MASK];
            }
            sender[i] = '\0';
            pos = gsm_rec_check("\r\n", pos, newpos);
            if (gsmreceived[(pos + 1) & GSM_RECPOS_MASK] == 'L' && gsmreceived[(pos + 2) & GSM_RECPOS_MASK] == 'o' && gsmreceived[(pos + 3) & GSM_RECPOS_MASK] == 'c') {
                pos = gsmrecpos;
                gsm_command("at+cgpsinfo\r\n", 1);
                pos = gsm_rec_check("+CGPSINFO", pos, gsmrecpos);
                if (gsmreceived[(--pos + 10) & GSM_RECPOS_MASK] != ',') {
                    // GPS stuff
                    gsm_send_sms("Locg:Not setup yet", sender);
                } else {
                    pos = gsmrecpos;
                    gsm_command("at+cassistloc=1\r\n", 0);
                    while(!gsm_rec_check("+CASS", pos, gsmrecpos));
                    newpos = gsm_rec_check("\n", pos, gsmrecpos);
                    pos = gsm_rec_check(":", pos, gsmrecpos);
                    //if (gsmreceived[(--pos) & GSM_RECPOS_MASK] != '\r') {
                    if (newpos - pos > 5) {
                        // cassistloc stuff
                        location[0] = 'L';
                        location[1] = 'o';
                        location[2] = 'c';
                        location[3] = 'c';
                        location[4] = ':';
                        for (i = 0; i < 20; i++) {
                            location[i + 5] = gsmreceived[(--pos + 1 + i) & GSM_RECPOS_MASK];
                        }
                        location[25] = '\0';
                        gsm_send_sms(location, sender);
                    } else {
                        gsm_send_sms("Err:No location found", sender);
                    }
                }
                //gsm_send_sms("Err:No location found", sender);
                PJOUT ^= 0x40;
            } else {
                gsm_send_sms("Autoresponse", sender);
            }
            oldsmscount += 1;
        }
        for (i = 0; i < 20; i++) {
            gsm_delay();
        }

        if (messgcheck) {
            //if (blue_rec_check("6C", oldbluerecpos, bluerecpos)) {
            //    PJOUT ^= 0x40;
            //    oldbluerecpos = bluerecpos;
            //    messgcheck = 0;
            //}
            PJOUT ^= 0x40;
            messgcheck = 0;
        }
        if (advertise == 0) {
            blue_command("A\r\n");
            advertise = 1;
        }
    }
}

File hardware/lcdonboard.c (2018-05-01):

//***************************************************************************************
// MSP430 UART connection to the cell modem
//***************************************************************************************
#include <msp430.h>

void lcd_command(char val, int ncom) {
    //UCB0TXBUF = 0xaa;
    //while(UCB0STATW & 0x1);
    UCB0TXBUF = 0x1f + (ncom << 6);
    while(UCB0STATW & 0x1);
    UCB0TXBUF = val & 0xf;
    while(UCB0STATW & 0x1);
    UCB0TXBUF = (val >> 4) & 0xf;
    while(UCB0STATW & 0x1);
}

void showhello(void) {
    // show "hello"
    lcd_command(0x48, 1);
    lcd_command(0x65, 1);
    lcd_command(0x6C, 1);
    lcd_command(0x6C, 1);
    lcd_command(0x6F, 1);
}

void fill_up_10(void) {
    int index = 0;
    for (index = 0;index < 10;index++) {
        lcd_command(0x20, 1);
    }

}

void whatdowedo(void) {
    //delay
    long int i1 = 20000;
    long int i2= 10000;
    while (i1 >0) {
        while (i2>0) {
            i2--;

        }
        i1--;


    }


    // put the left out one character
    lcd_command(' ', 1);
    // print message
    lcd_command('w', 1);
    lcd_command('h', 1);
    lcd_command('a', 1);
    lcd_command('t', 1);
    lcd_command(' ', 1);
    lcd_command('a', 1);
    lcd_command('r', 1);
    lcd_command('e', 1);
    lcd_command(' ', 1);
    lcd_command(' ', 1);
    fill_up_10();
    lcd_command('w', 1);
    lcd_command('e', 1);
    lcd_command(' ', 1);
    lcd_command('g', 1);
    lcd_command('o', 1);
    lcd_command('i', 1);
    lcd_command('n', 1);
    lcd_command('g', 1);
    lcd_command(' ', 1);
    lcd_command(' ', 1);
    fill_up_10();
    lcd_command('t', 1);
    lcd_command('o', 1);
    lcd_command(' ', 1);
    lcd_command('d', 1);
    lcd_command('o', 1);
    lcd_command(0x3f, 1);
    lcd_command(' ', 1);
    lcd_command(' ', 1);
    lcd_command(' ', 1);
    lcd_command(' ', 1);
    fill_up_10();
    fill_up_10();
}

void main(void) {
    volatile unsigned int i = 100;

    WDTCTL = WDTPW | WDTHOLD;               // Stop watchdog timer
    PM5CTL0 &= ~LOCKLPM5;                   // Disable the GPIO power-on default high-impedance mode
                                            // to activate previously configured port settings


    //chip select pull high
    P1DIR |= 0x20;
    P1OUT |= 0x20;
    // chip select pull low
    P1OUT &= ~0x20;
    // Reset through GPIO
    P6DIR |=0x01;
    P6OUT &= ~0x01;
    do i--;
    while (i != 0);


    P6OUT |= 0x01;

    //P1DIR |= 0x40;
    P1SEL0 |= 0x50;
   // P1SEL1 &= ~0x40;
    //P1OUT |= 0x40;
    //P1OUT &= ~0x40;
    //try mosi as gpio


    CSCTL0 = 0xa500;
    CSCTL1 = 0x08;
    CSCTL3 = 0x03;


    UCB0CTLW0 |= 0x1;
    UCB0CTLW0 |= 0x4d03;
    //try new setting
    //UCB0CTLW0 |= 0x0d03;
    UCB0BRW = 0x8;
    UCB0CTLW0 &= ~0x1;

    lcd_command(0x3a, 0);
    lcd_command(0x09, 0);
    lcd_command(0x06, 0);
    lcd_command(0x1e, 0);
    lcd_command(0x39, 0);
    lcd_command(0x1b, 0);
    lcd_command(0x6e, 0);
    lcd_command(0x56, 0);
    lcd_command(0x7a, 0);
    lcd_command(0x38, 0);
    lcd_command(0x0f, 0);


    lcd_command('y', 1);
    lcd_command('o', 1);
    lcd_command(',', 1);
    lcd_command('p', 1);
    lcd_command('e', 1);
    lcd_command('o', 1);
    lcd_command('p', 1);
    lcd_command('l', 1);
    lcd_command('e', 1);
    lcd_command(' ', 1);
    fill_up_10();
    lcd_command('t', 1);
    lcd_command('h', 1);
    lcd_command('e', 1);
    lcd_command(' ', 1);
    lcd_command('L', 1);
    lcd_command('C', 1);
    lcd_command('D', 1);
    lcd_command(0x27, 1);
    lcd_command('s', 1);
    lcd_command(' ', 1);
    fill_up_10();
    lcd_command('s', 1);
    lcd_command('t', 1);

    lcd_command('i', 1);
    lcd_command('l', 1);
    lcd_command('l', 1);
    lcd_command(' ', 1);
    lcd_command('n', 1);
    lcd_command('o', 1);
    lcd_command('t', 1);
    lcd_command(' ', 1);
    fill_up_10();
    lcd_command(' ', 1);
    lcd_command('w', 1);

    lcd_command('o', 1);
    lcd_command('r', 1);
    lcd_command('k', 1);
    lcd_command('i', 1);
    lcd_command('n', 1);
    lcd_command('g', 1);
    lcd_command(' ', 1);
  // leave one slot , or the cursor rewinds to the start of LCD which covers
  // the first character
    fill_up_10();

    whatdowedo();
    // pull high again chip select
    P1OUT |= 0x20;
    // choose character table
//    lcd_command(0x3a, 0);
//    lcd_command(0x72, 0);
//    lcd_command(0x00, 0);
//    lcd_command(0x38, 0);
//set the content
//    lcd_command(0x0f, 0);
//
//
//    lcd_command(0x0f, 0);

//    for(;;) {
//        UCB0TXBUF = 0xaa;
//        while(UCB0STATW & 0x1);
//        UCB0TXBUF = ~0xaa;
//        i = 6110;
//        do i--;
//        while(i != 0);
//    }
}

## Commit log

2018-02-22 adding the schematic
    [ECE477_schematic.sch]
2018-02-23 Prototype app, can send and receive SMS messages
2018-03-02 adding the schematic and brd file from week 8 (midterm review)
    [ECE477_schematic.brd, ECE477_schematic.sch]
2018-03-10 the ordered PCB schematic and layout files
    [ECE477_schematic.brd, ECE477_schematic.sch]
2018-03-30 03/29/2018 image of schematic
2018-04-19 Adding all current app files
2018-04-30 confirmed to be the latest
    [ECE477_schematic.brd]
2018-04-30 Adding homework files
    [5_BillOfMaterials.xlsx]

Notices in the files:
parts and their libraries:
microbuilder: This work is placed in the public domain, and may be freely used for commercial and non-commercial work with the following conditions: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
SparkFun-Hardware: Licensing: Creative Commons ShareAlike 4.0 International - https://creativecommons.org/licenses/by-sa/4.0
